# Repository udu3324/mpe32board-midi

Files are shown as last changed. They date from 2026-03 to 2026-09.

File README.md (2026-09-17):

# mpe32board-midi
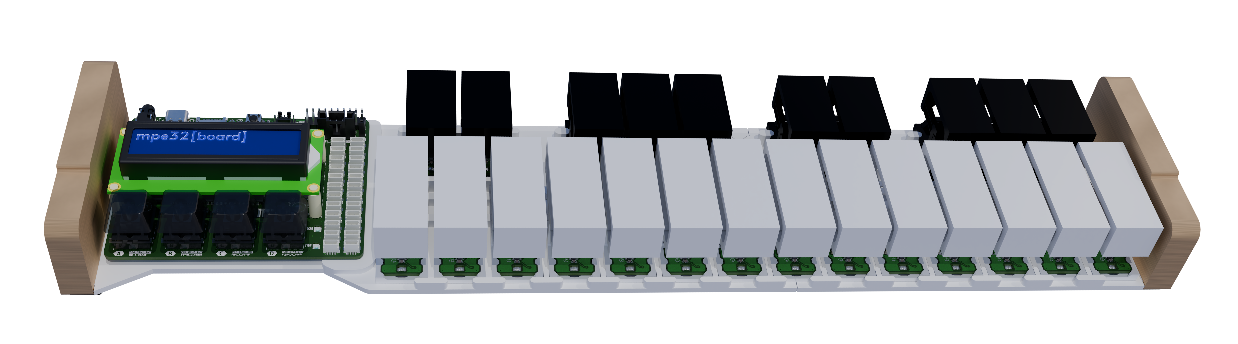
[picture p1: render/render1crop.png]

An expressive midi controller that has onboard sound processing with an expandable and hackable nature.
(v2 of [stm32pe-midi](https://github.com/udu3324/stm32pe-midi))

 * Built in DSP
 * Support for Programs and Sequencer
 * Hacker Header Exposed GPIO
 * Micro-SD Card Support
 * Onboard SDRAM for extended recording/memory

## Purpose
After making the [stm32pe-midi](https://github.com/udu3324/stm32pe-midi), I wanted to reflect at the problems I faced and the feature set I sacrificed out of it originally. I wanted to learn how ram works and the correct way to implement it, which I did for this project. I also wanted something that was more polished and structured better as the pcb dictated the rest of the design which lead to unfortunate design decisions. I instead designed everything in module-like components to allow more expansion and flexibility in the future.

## Zine Page
Some information is redacted on this export, DM me for the full version!
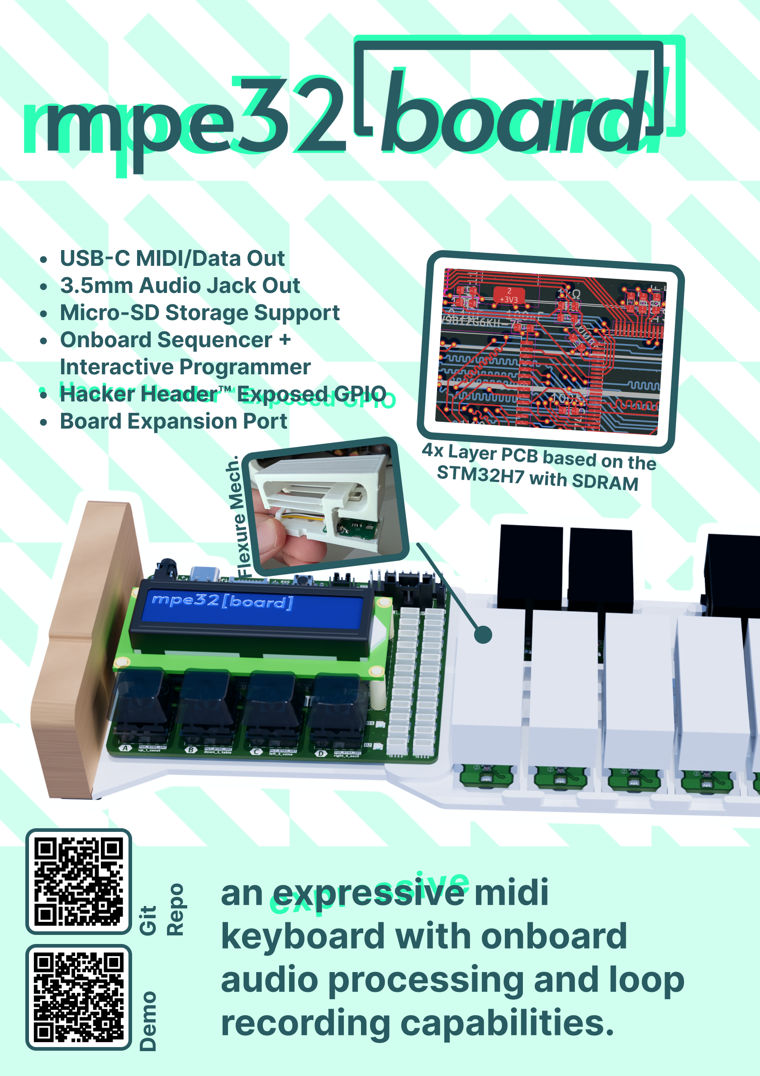
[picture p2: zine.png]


## Firmware
The firmware uses the stm32cubemx software to generate a .ioc of its pinout functions and its cmake gcc code template. I then chose Visual Studio Code as the choice of my IDE to code the rest in C/C++.

There is sample code [here](https://gist.github.com/udu3324/de9aada8e3ea0addc13870c6bbbebc0f) for trying out the mpe32sensors standalone on the Arduino platform.
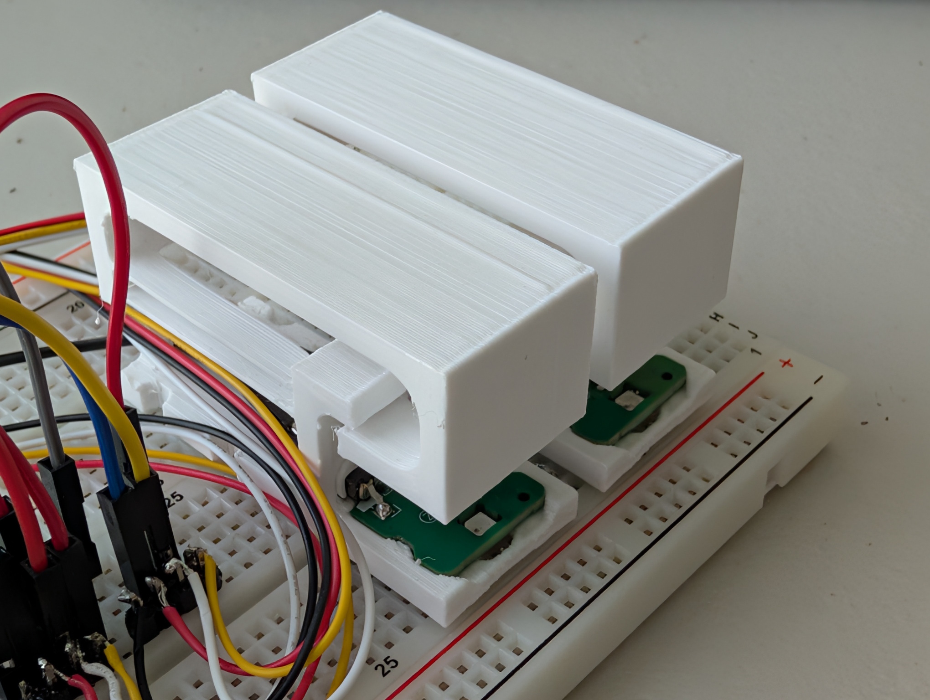
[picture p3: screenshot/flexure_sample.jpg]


### Libraries Used
 * https://github.com/hathach/tinyusb
 * https://github.com/jtainer/i2c-mux
 * https://github.com/berndoJ/libneopixel32
 * https://github.com/devOramaMan/stm32_TMAG5273 (modified/fixed)
 * https://github.com/alixahedi/i2c-lcd-stm32

## CAD
### Case
The case is a 3 part 3d-printed case that is screwed together with m3 screws, both being self-tapped and heat-set inserts. There are two wood block accents (or plywood) on the side screwed in too.
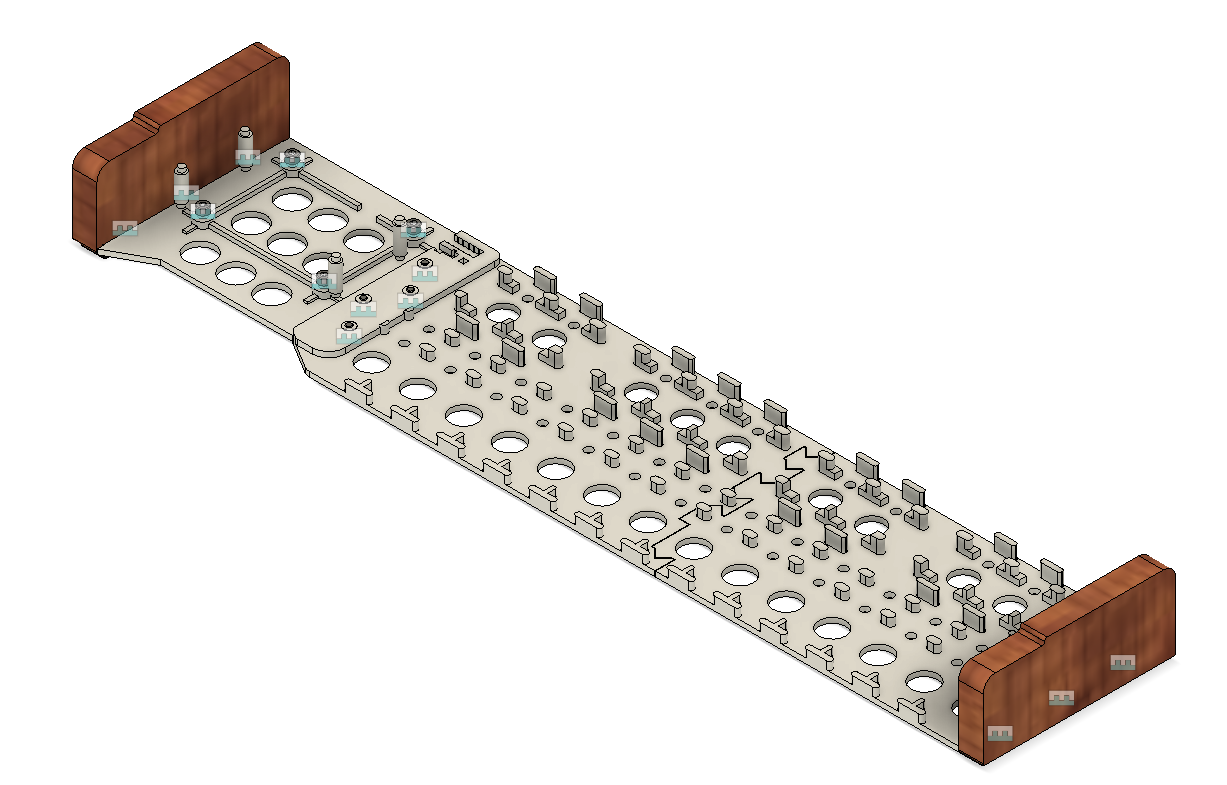
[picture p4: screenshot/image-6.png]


Each key is press fit and can also be screwed in with a m3 screw and nut if needed.
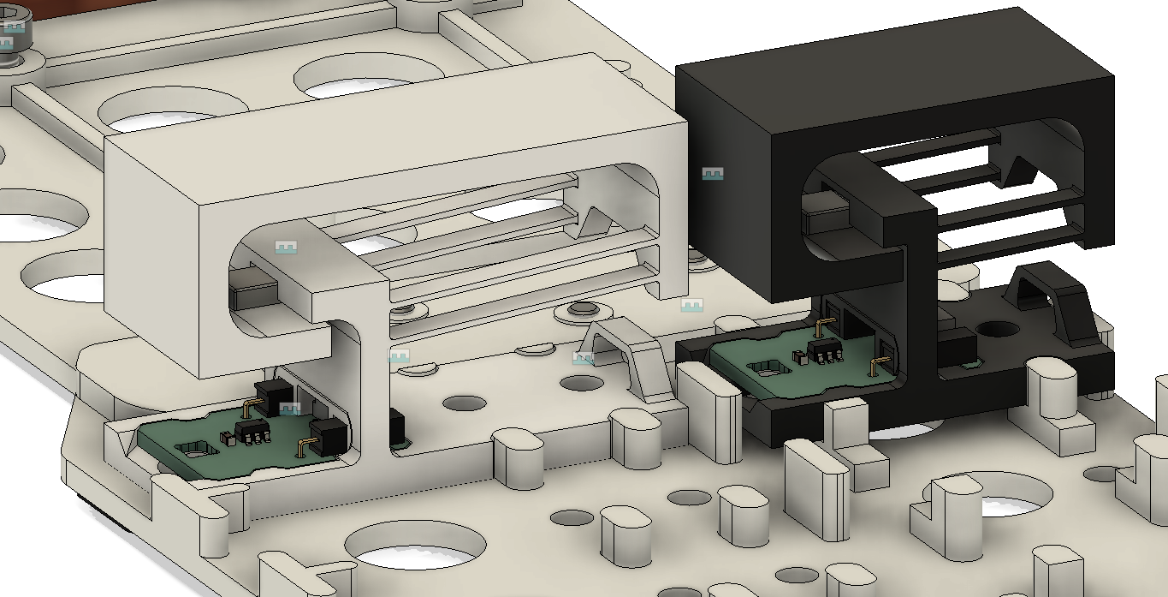
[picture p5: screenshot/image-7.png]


Due to my 3d-printer being too small, I have to cut the board in half to print. This is later adhered with uv-glue.
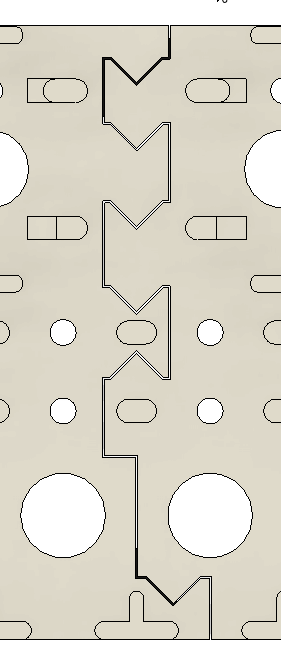
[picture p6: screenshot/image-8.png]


### Keys
The keys are compliant mechanisms that are designed to be 3d-printed with the least amount of post-processing. The flexure allows the key to move up and down as well as twist to allow pitch shifting.
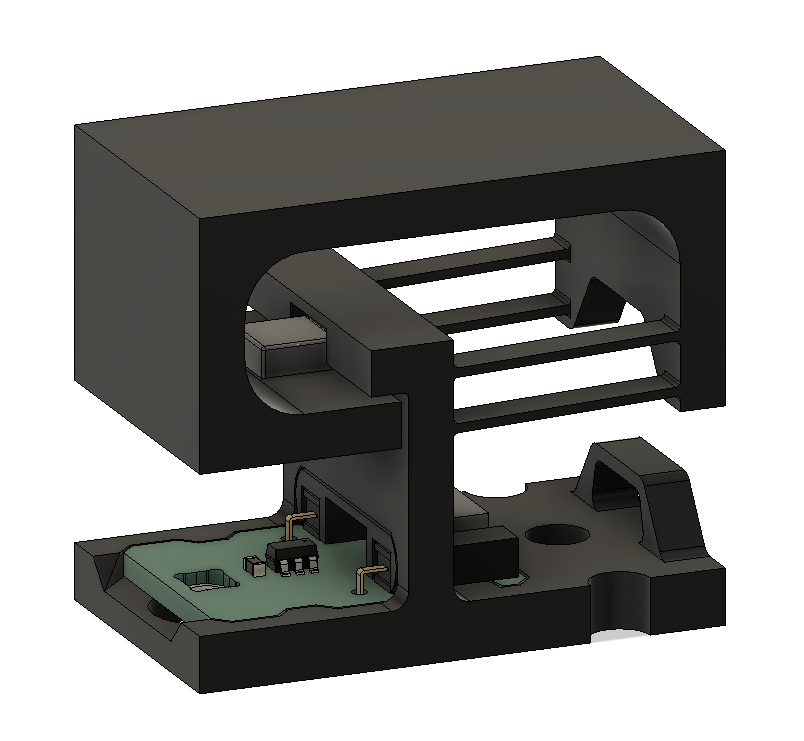
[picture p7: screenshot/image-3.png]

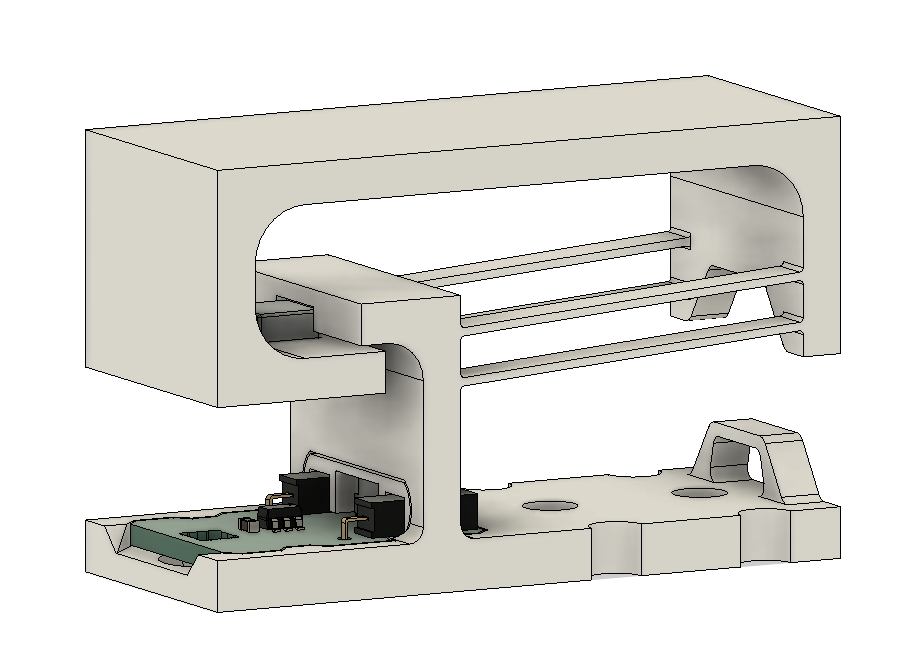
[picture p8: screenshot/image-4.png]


Another printed piece is included to hold down and fix the stm32sensor pcb in place.
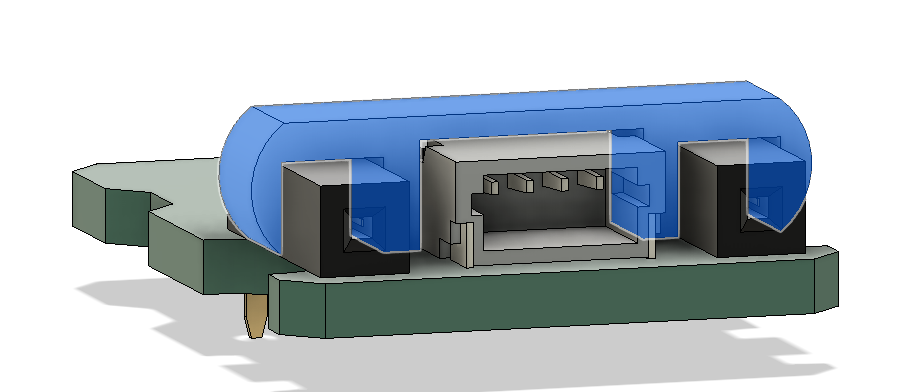
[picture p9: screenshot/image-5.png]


## PCB
I split my design into two boards. One being the "motherboard" called the stm32board which connects everything and has the mcu/ram/jtag for central control. The other is the sensor boards called the stm32sensor which connects through one of the 24 JST-SH-4x connectors that are on their own i2c line.

### stm32[board]
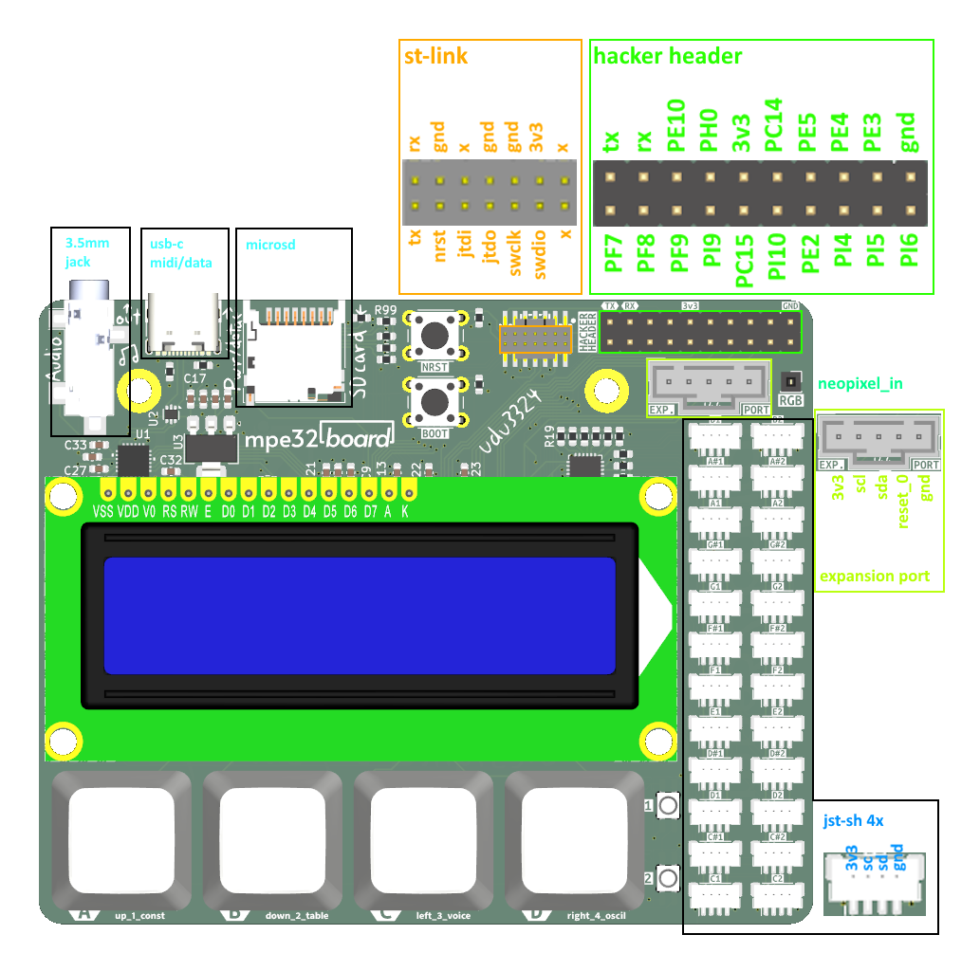
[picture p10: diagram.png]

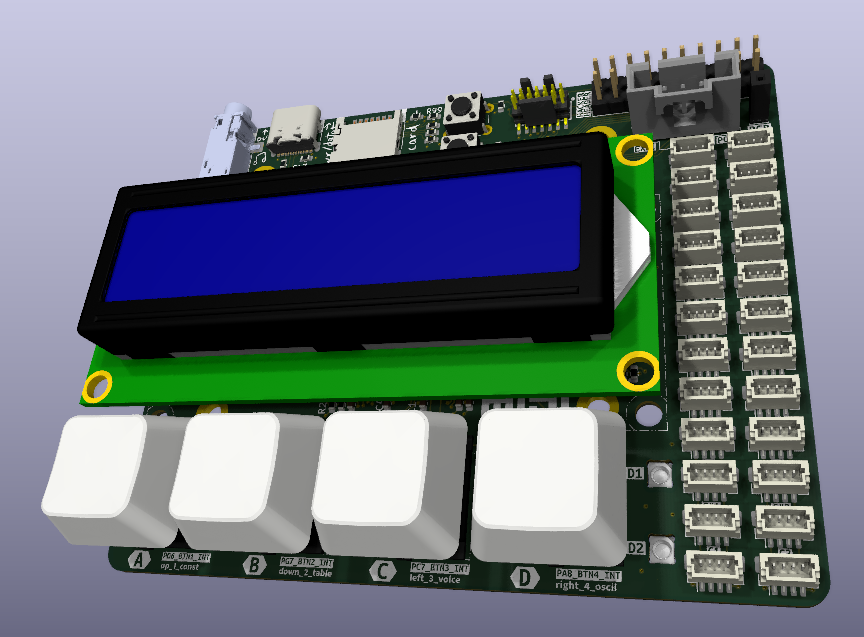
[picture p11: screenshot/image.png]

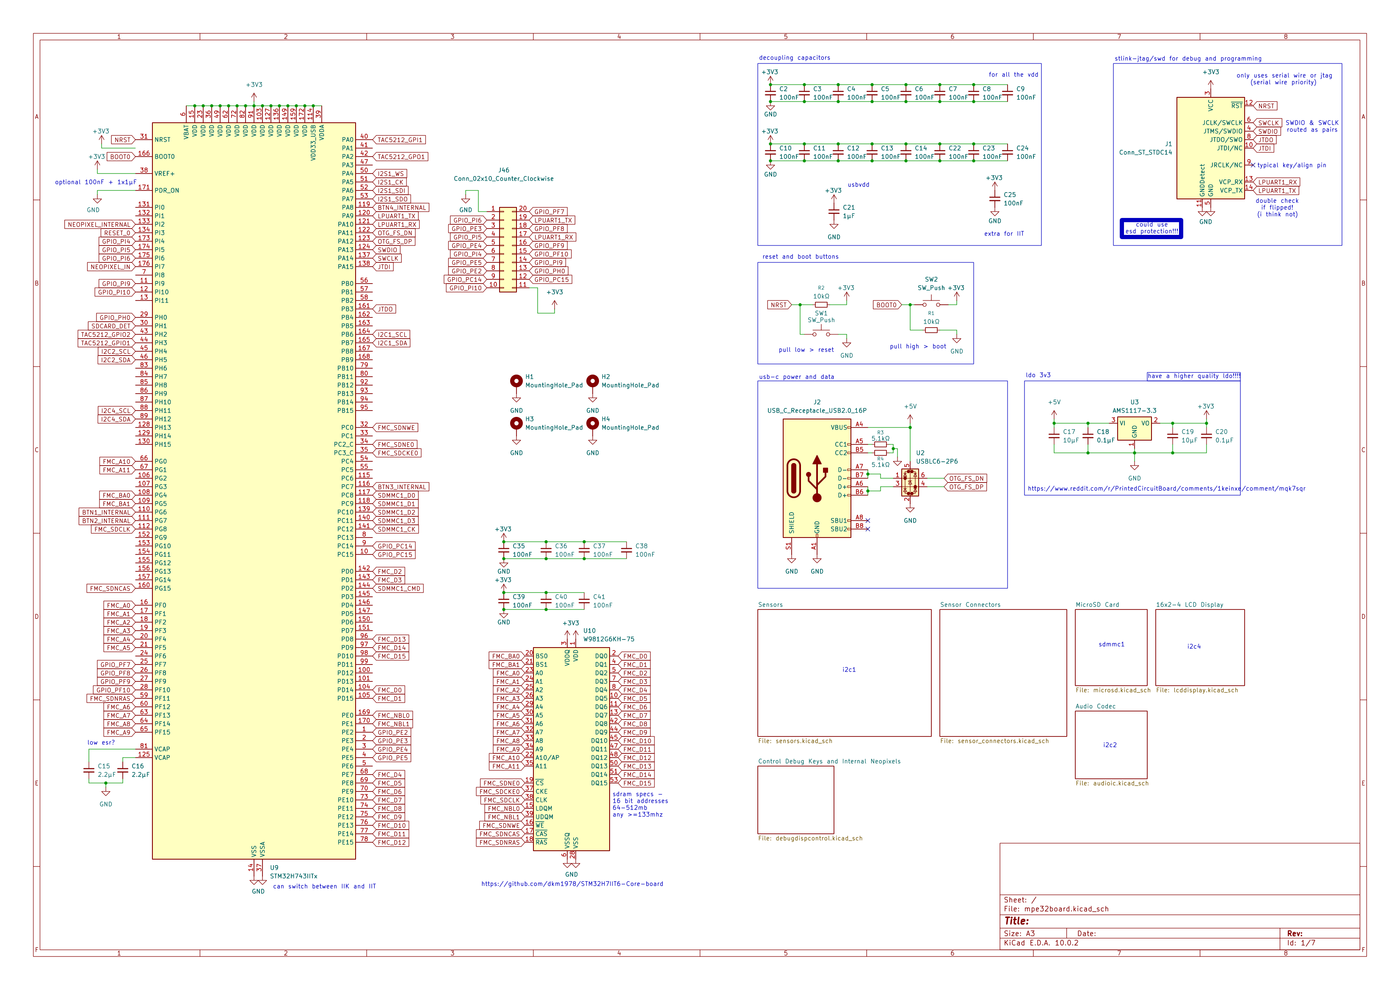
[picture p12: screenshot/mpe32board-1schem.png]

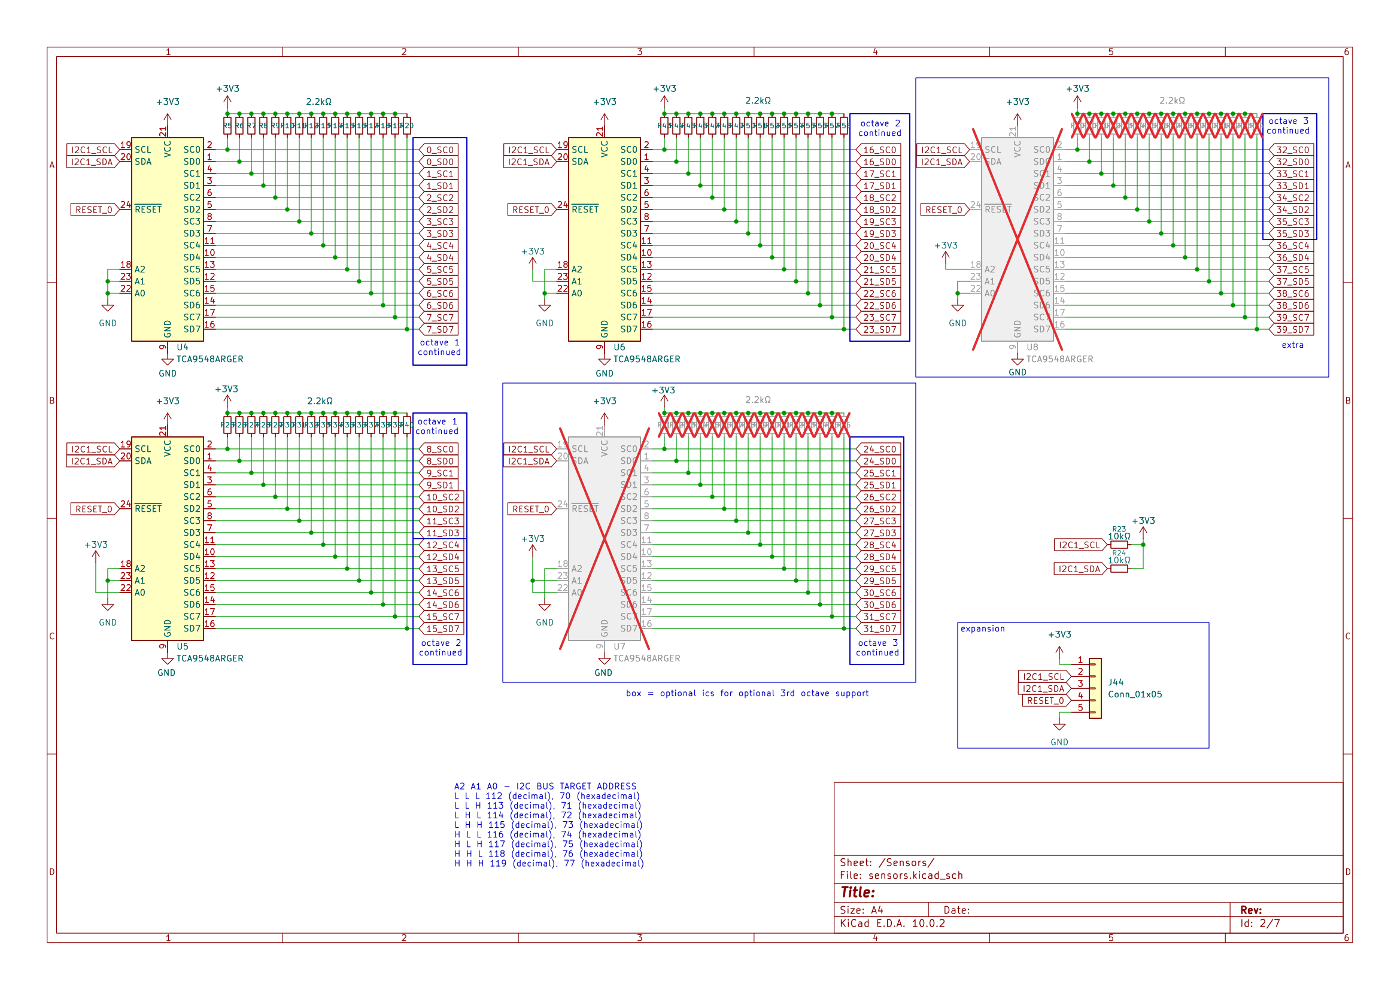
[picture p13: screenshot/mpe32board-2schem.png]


### stm32[sensor]
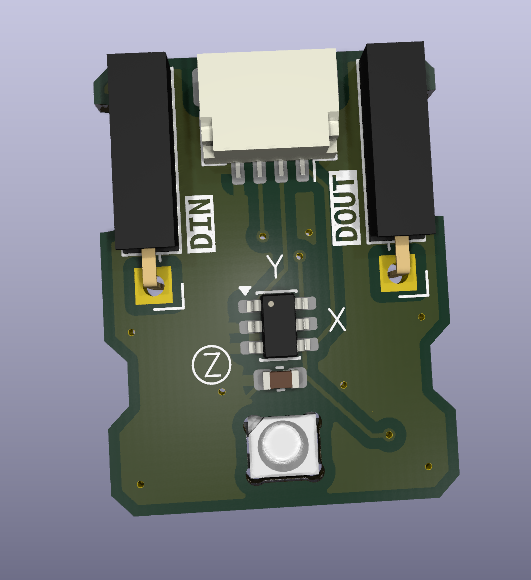
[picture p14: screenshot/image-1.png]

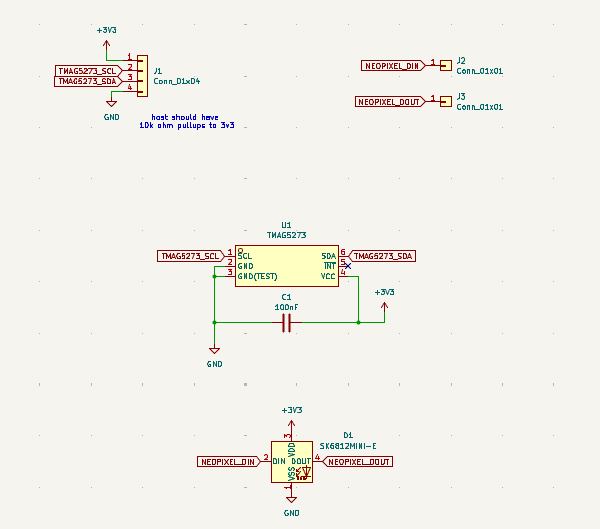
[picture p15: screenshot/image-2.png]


## BOM
The Bill of Materials can be viewed [here](https://docs.google.com/spreadsheets/d/1Ah6NNKW-CTIdOJtxNPdxd3ZnzDfgMl2LX2XapnXmrVo/edit).

### Build Steps
1. Get all materials ready and 3d printed
2. Post-process any 3d-prints if needed and insert heat set inserts for m3 screws
3. Assemble the pcb if not PCBA
4. Assemble all sensor boards into key housings and holder
5. Add LCD to stm32board and solder onto header
6. Assemble all keys and stm32board onto case, while also wire routing carefully
7. Screw on accent wood blocks
8. Flash firmware onto board
9. Done! Plug and play into your host device and favorite DAW

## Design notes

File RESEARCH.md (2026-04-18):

mpe32board-midi research

# features

midi out to pc
audio out to pc (onboard synth/dsp)
gpio exposed
easy tinkering with

(optional) microsd slot

# electronics

## main board

stm32h743 (good processing power)

i need a mcu that is:

* in stock
* supports sdram
* has good flash space

stm32h743ag
stm32h743ai
stm32h743ig

stm32h743xg
stm32h743xi

stm32h753ii

stm32h753ai (4 in stock) (lfbga169)
stm32h743ii (2k in stock) (lqfp176)
stm32h753xi (187 in stock) (tfbga240+25)

going with stm32h743ii

^ good option, better than the 750 which has little flash

supports a 16x2 lcd display (headers for it)

https://community.st.com/t5/stm32-mcus/how-to-set-up-the-fmc-peripheral-to-interface-with-the-sdram/ta-p/49457
https://www.youtube.com/watch?v=h28D4AaPSjg
64mb ram (SDRAM) (look at 3.15 on datasheet)
has to run 100mhz, can be underclocked, 90-tfbga footprint
also i hope i can trace this well

a bunch of TCA9548A i2c muxes
!!!!!!!! check if memory could take up too much io for the muxes i need
^ im pretty sure im fine as the muxes can hardware set their addresses

https://electronics.stackexchange.com/questions/595103/stdc14-connector-pinout-for-st-link-v3-for-swd-debugging
stlink for easy debugging and flashing (under jtag/swd)
either use 10pin or 20pin
still requires external power (from usb c)

https://www.phippselectronics.com/interface-an-sd-card-through-sdio-on-the-stm32-blackpill-part-1/

microsd support

## hall effect sensor board

tmag5273
^ capacitor for it

https://www.thevfdcollective.com/blog/stm32-and-sk6812-rgbw-led
(optional) neopixel? (supply with 3v3 and 3v3 logic)

connector out > 3v3, gnd, tmag out, neopixel in, neopixel out (5)
OR
connector out > 3v3, gnd, tmag out
connector L > neopixel in
connector R > neopixel out (chain-like connection)

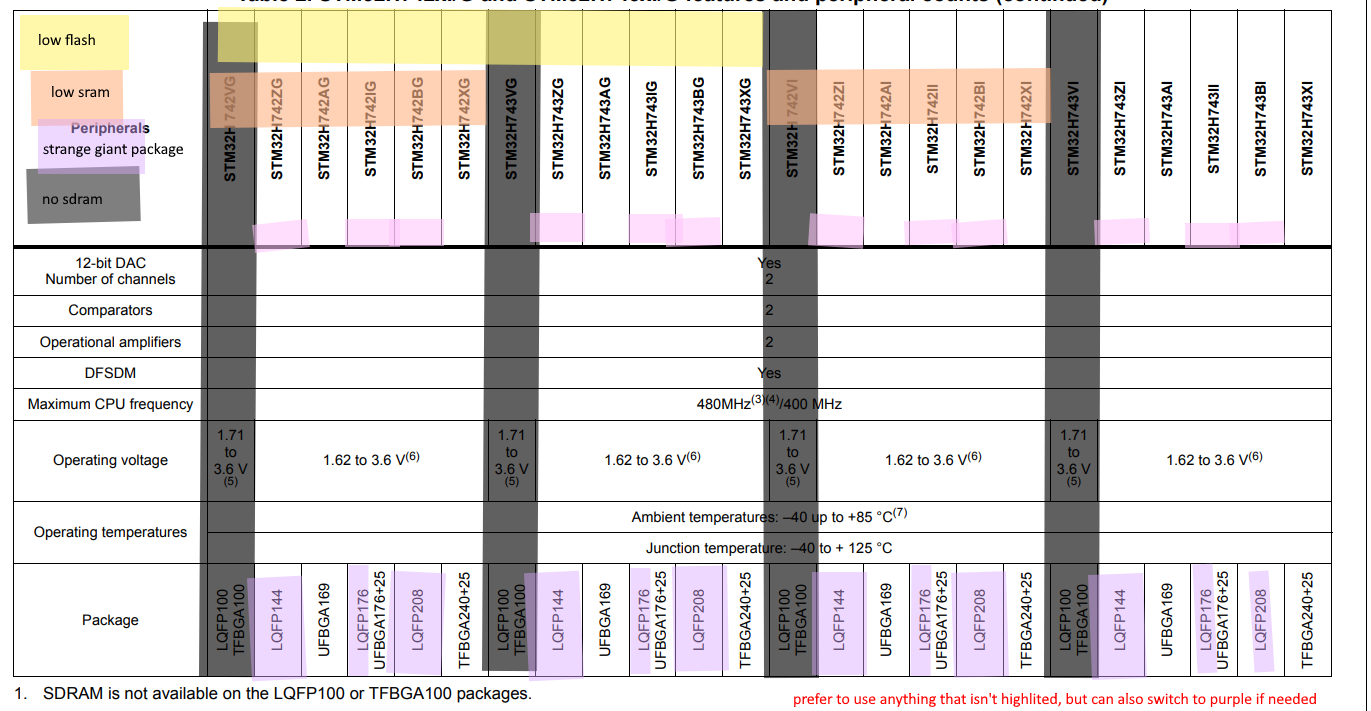
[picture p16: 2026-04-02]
stm32h7.png

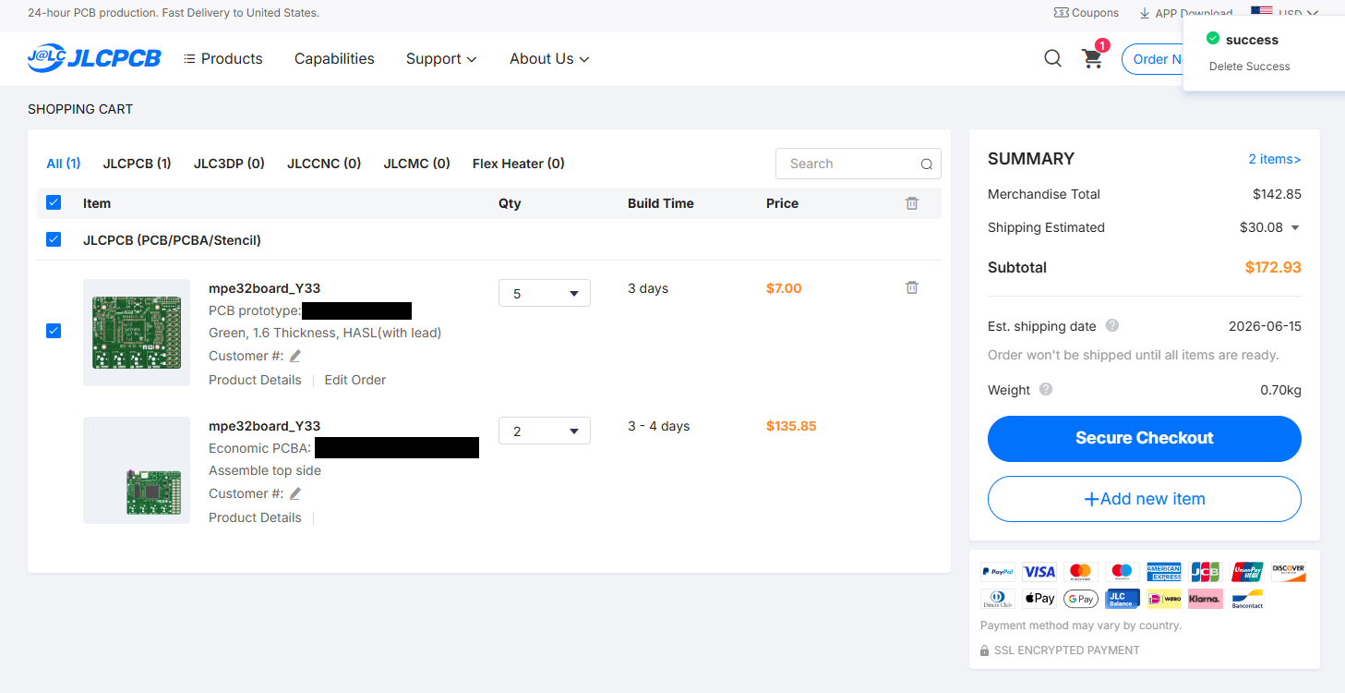
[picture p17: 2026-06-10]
cart/jlcpcb-mpe32board subtotal.png

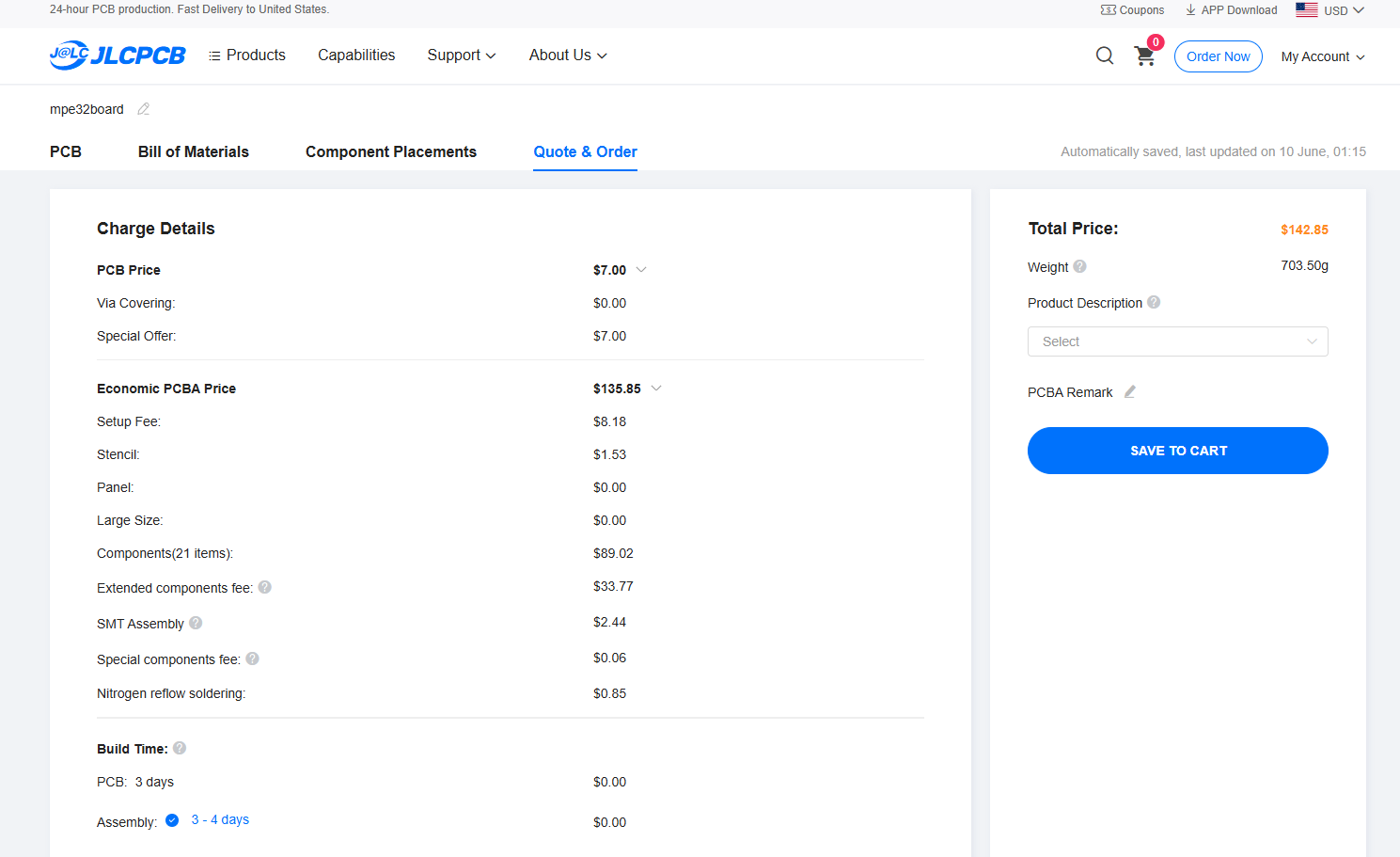
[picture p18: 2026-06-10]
cart/jlcpcb-mpe32board price breakdown.png

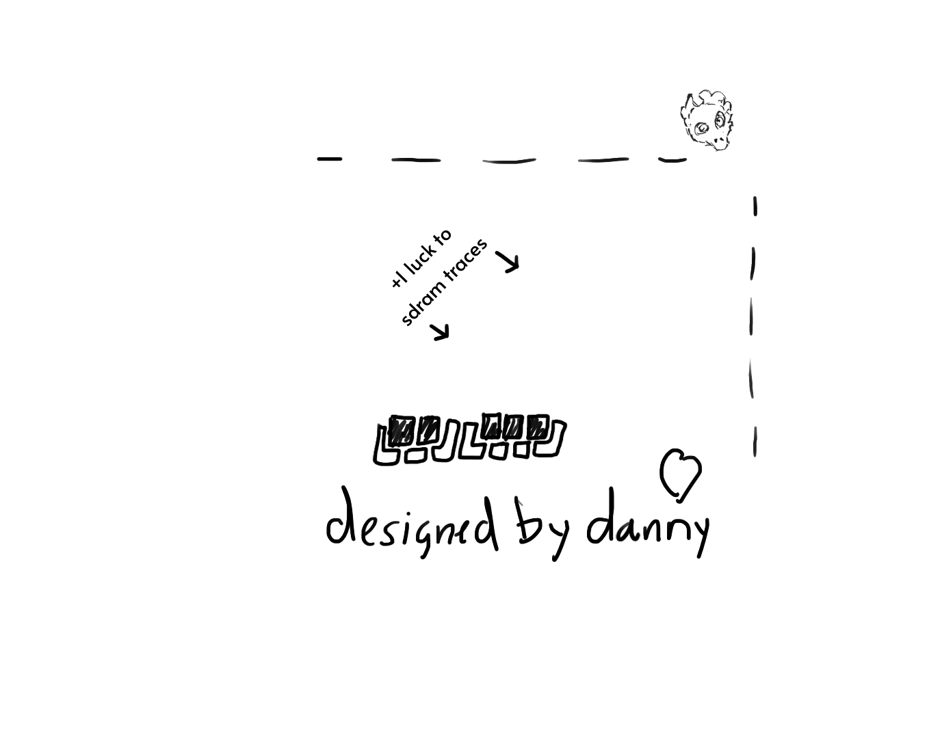
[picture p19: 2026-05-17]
pcb/mpe32board-B_Silkscreen.png

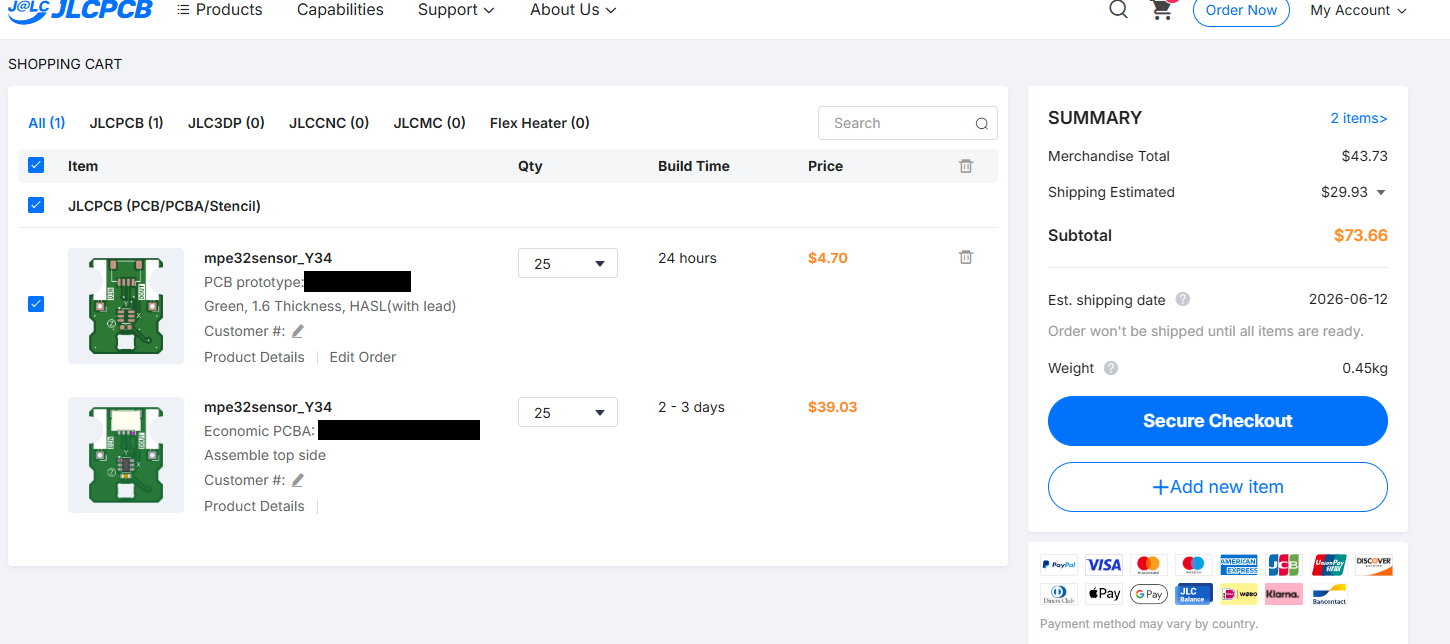
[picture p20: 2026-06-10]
cart/jlcpcb-mpe32sensor subtotal.png

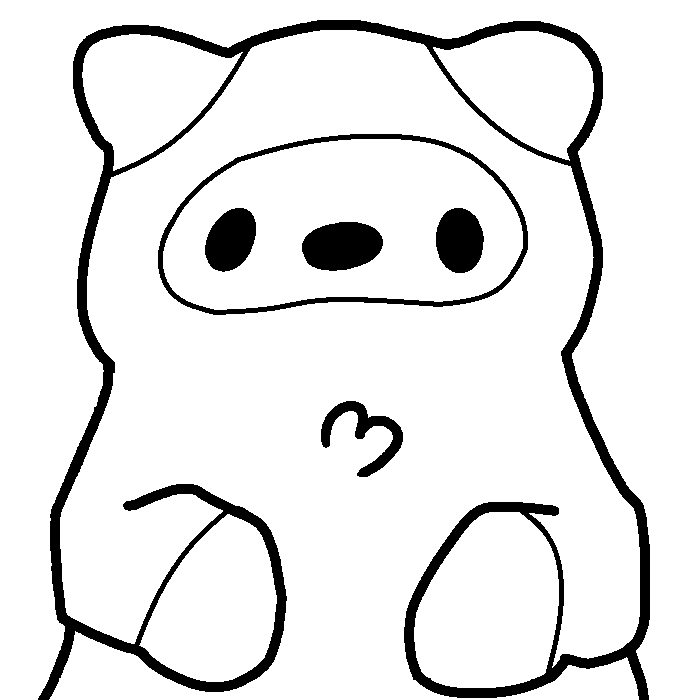
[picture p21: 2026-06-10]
pcb/soup.png

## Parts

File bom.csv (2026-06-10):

Part | Description | URL | URL Note | Price | Quantity (reflecting part q, not product q) | Sourcing | Subtotals
neodymium magnet | 5mm cube | https://www.amazon.com/dp/B0GTTXC3FT | pack of 60 | 9.99 | 24 |  | 9.99
Key Large | 3d printed |  |  |  | 14 | will print
Key Small | ~ |  |  |  | 10 | will print
LCD Spacer | ~ |  |  |  | 4 | will print
Case Right | ~ |  |  |  | 1 | will print
Case Left | ~ |  |  |  | 1 | will print
Case | ~ |  |  |  | 1 | will print
UV Glue |  | https://www.amazon.com/dp/B018IBEHQU |  | 13.95 | 1 | already have
plywood | 12mm thick | https://makerstock.com/products/baltic-birch-plywood-uv-prefinished-b-bb-finished-both-sides-copy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 | 3x3in | 4.95 | 2 | already have | 9.9
m3 heatset inserts |  | https://www.adafruit.com/product/4255 | pack of 50 | 5.95 | 8 |  | 5.95
m3 6mm screw |  | https://www.mcmaster.com/91292A111/ | pack of 100 | 12.71 | 14 |  | 12.71
m3 4mm screw |  | https://www.mcmaster.com/91292A109/ | pack of 50 | 3.86 | 14 | already have | 3.86
CN0295D | lcd screen | https://www.digikey.com/en/products/detail/sunfounder/CN0295D/18668612 |  | 9.13 | 1 | already have | 9.13
SK6812MINI-E |  |  |  |  | 4 | already have | 2.95
hotswap switch socket |  | https://www.adafruit.com/product/4958 | comes in pack of 20 | 4.95 | 4 |  | 4.95
key switches |  | https://www.aliexpress.us/item/3256808099380919.html?curPageLogUid=pP8MKuu5kHOB | comes in a pack of 8 (priced welcome deal) | 0.99 | 4 | already have | 0.99
4x 2.54 male header |  | https://www.mouser.com/ProductDetail/Samtec/MTSW-104-07-F-S-155?qs=PB6%2FjmICvI1FPDxv9fFH%252BQ%3D%3D |  | 0.31 | 1 | already have | 0.31
5x female molex conn |  | https://www.mouser.com/ProductDetail/Molex/171971-0005?qs=lc2O%252BfHJPVaHzX1glCYU2g%3D%3D |  | 1.37 | 1 |  | 1.37
1x 2.54 female header |  | https://www.mouser.com/ProductDetail/Samtec/SSA-101-S-G?qs=rU5fayqh%252BE15kAKORo1KGg%3D%3D |  | 0.41 | 1 |  | 0.41
10x2 2.54 male header |  | https://www.mouser.com/ProductDetail/Amphenol-FCI/77313-824-10LF?qs=xJiur%252Bgubk0jGbvndcgeKw%3D%3D |  | 0.56 | 1 |  | 0.56
6mm push button |  | https://www.mouser.com/ProductDetail/CK/PTS645SH43-2-LFS?qs=rqnA19JZHeR58R%2F%2FUQmolQ%3D%3D |  | 0.27 | 2 | already have | 0.54
PCB board | JLCPCB PCBA |  | grand total | 254.56 | 1 |  | 254.56
SK6812MINI-E |  | https://www.mouser.com/ProductDetail/Adafruit/4960?qs=pBJMDPsKWf1Q%252BqeEoLnQjA%3D%3D | comes in pack of 10 | 2.95 | 24 |  | 8.85
2.54 1x female header | needs to be bent to horizontal | https://www.mouser.com/ProductDetail/Samtec/SSA-101-S-G?qs=rU5fayqh%252BE15kAKORo1KGg%3D%3D | 24*2 needed | 0.41 | 48 |  | 19.68
PCB sensor | JLCPCB PCBA |  | grand total (can't order exactly 24) | 80.54 | 25 |  | 80.54
 |  |  |  |  |  |  | 427.25 | TOTAL
 |  |  |  |  |  |  | 399.57 | TOTAL without the things i have already

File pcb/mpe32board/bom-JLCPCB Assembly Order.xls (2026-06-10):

JLCPCB BOM Tool - BOM Matching
BOM name：bom-JLCPCB Assembly Order.xlsx |  |  | Download Time：2026-06-10 14:11:54 |  |  |  | * Our matching results are updated in real-time, but stock and prices may change. If it's been over 24 hours, please re-match before placing your order.
PCB Assembled Qty：5 |  |  | Est. Total Price：89.6339
Your BOM |  |  |  |  | Matched Parts |  |  |  |  |  |  | Order Information
Top Designator | Bottom Designator | Comment | Footprint | JLCPCB Part # | Matches | Part # | Manufacturer | Footprint | Description | Category | Warning | JLCPCB Part # | Product link | Lib Type | Qty | Source | Total Price ($)
C10,C11,C12,C13,C14,C2,C22,C23,C24,C25,C3,C35,C36,C37,C38,C39,C4,C40,C41,C5,C6,C7,C8,C9 |  | 100nF | 0603 |  | Unconfirmed | CC0603KRX7R9BB104 | YAGEO | 0603 | 100nF 50V X7R ±10% 0603 Multilayer Ceramic Capacitors MLCC - SMD/SMT ROHS | Multilayer Ceramic Capacitors MLCC - SMD/SMT | 1.Multiple lines in the BOM have been matched to the same part. Please check if the matching is correct. ; | C14663 | https://jlcpcb.com/partdetail/YAGEO-CC0603KRX7R9BB104/C14663 | Basic | 58 | 58 JLCPCB | 0.6148
C18,C20,C27,C29,C31 |  | 0.1μF | 0603 |  | Unconfirmed | CC0603KRX7R9BB104 | YAGEO | 0603 | 100nF 50V X7R ±10% 0603 Multilayer Ceramic Capacitors MLCC - SMD/SMT ROHS | Multilayer Ceramic Capacitors MLCC - SMD/SMT | 1.The comment (CC0603KRX7R9BB104) of this part does not match the one (0.1μF) provided in your BOM. Please confirm; 2.Multiple lines in the BOM have been matched to the same part. Please check if the matching is correct. ; | C14663 | https://jlcpcb.com/partdetail/YAGEO-CC0603KRX7R9BB104/C14663 | Basic | 58 | 58 JLCPCB | 0.6148
C15,C16 |  | 2.2μF | 0603 |  | Unconfirmed | CL10A225KO8NNNC | Samsung Electro-Mechanics | 0603 | 16V 2.2uF X5R ±10% 0603 Multilayer Ceramic Capacitors MLCC - SMD/SMT ROHS | Multilayer Ceramic Capacitors MLCC - SMD/SMT | 1.The comment (CL10A225KO8NNNC) of this part does not match the one (2.2μF) provided in your BOM. Please confirm; | C23630 | https://jlcpcb.com/partdetail/24366-CL10A225KO8NNNC/C23630 | Basic | 4 | 4 JLCPCB | 0.0368
C17,C19,C26,C30,C32 |  | 10μF | 0603 |  | Unconfirmed | CL10A106KP8NNNC | Samsung Electro-Mechanics | 0603 | 10V 10uF X5R ±10% 0603 Multilayer Ceramic Capacitors MLCC - SMD/SMT ROHS | Multilayer Ceramic Capacitors MLCC - SMD/SMT | 1.The comment (CL10A106KP8NNNC) of this part does not match the one (10μF) provided in your BOM. Please confirm; | C19702 | https://jlcpcb.com/partdetail/20411-CL10A106KP8NNNC/C19702 | Basic | 10 | 10 JLCPCB | 0.155
C21,C28 |  | 1μF | 0603 |  | Unconfirmed | CL10A105KB8NNNC | Samsung Electro-Mechanics | 0603 | 1uF 50V X5R ±10% 0603 Multilayer Ceramic Capacitors MLCC - SMD/SMT ROHS | Multilayer Ceramic Capacitors MLCC - SMD/SMT | 1.The comment (CL10A105KB8NNNC) of this part does not match the one (1μF) provided in your BOM. Please confirm; | C15849 | https://jlcpcb.com/partdetail/16531-CL10A105KB8NNNC/C15849 | Basic | 4 | 4 JLCPCB | 0.0432
C33,C34 |  | 47μF | 0603 |  | Select by Customer | GRM188R60J476ME15D | Murata Electronics | 0603 | 47uF 6.3V X5R ±20% 0603 Multilayer Ceramic Capacitors MLCC - SMD/SMT ROHS | Multilayer Ceramic Capacitors MLCC - SMD/SMT | 1.The comment (GRM188R60J476ME15D) of this part does not match the one (47μF) provided in your BOM. Please confirm; | C140782 | https://jlcpcb.com/partdetail/152108-GRM188R60J476ME15D/C140782 | Extended | 8 | 8 JLCPCB | 1.0264
J1 |  | Conn_ST_STDC14 | CONN-SMD_14P-P1.27_FTSH-107-01-F-DV-K-P-TR |  | Select by Customer | FTSH-107-01-F-DV-K-P-TR | Samtec | SMD,P=1.27mm | -55℃~+125℃ 1.27mm 14P 2 2x7P 3.05mm 3.4A Black Gold Phosphor bronze Pin Header Surface Mount,Vertical SMD,P=1.27mm Pin Headers ROHS | Pin Headers | 1.The comment (FTSH-107-01-F-DV-K-P-TR) of this part does not match the one (Conn_ST_STDC14) provided in your BOM. Please confirm; | C5276598 | https://jlcpcb.com/partdetail/Samtec-FTSH_107_01_F_DV_K_PTR/C5276598 | Extended | 2 | 2 JLCPCB | 6.6228
J2 |  | USB_C_Receptacle_USB2.0_16P | USB_C_Receptacle_GCT_USB4105-xx-A_16P_TopMnt_Horizontal |  | Select by Customer | USB4105-GF-A-120 | Global Connector Technology | SMD | -40℃~+85℃ 1 16P 48V 5A Black Female Type-C USB 2.0 SMD USB Connectors ROHS | USB Connectors |  | C5184243 | https://jlcpcb.com/partdetail/5849584-USB4105_GF_A120/C5184243 | Extended | 2 | 2 JLCPCB | 1.9534
J10,J11,J12,J13,J14,J15,J16,J17,J18,J19,J20,J21,J22,J23,J24,J25,J26,J27,J4,J5,J6,J7,J8,J9 |  | Conn_01x04 | JST_SH_BM04B-SRSS-TB_1x04-1MP_P1.00mm_Vertical |  | Select by Customer | BM04B-SRSS-TB(LF)(SN) | JST | SMD,P=1mm | -25℃~+85℃ 1 1A 1mm 1x4P 3.6mm 4 4.25mm 4P 50V 6mm Auxiliary Solder Pin Copper alloy PA SR Surface Mount,Vertical Tin UL94V-0 White SMD,P=1mm Wire To Board Connector ROHS | Wire To Board Connector |  | C160390 | https://jlcpcb.com/partdetail/JST-BM04B_SRSS_TB_LF_SN/C160390 | Extended | 48 | 48 JLCPCB | 11.1216
J48 |  | Micro_SD_Card_Det_Hirose_DM3AT | microSD_HC_Hirose_DM3D-SF |  | Select by Customer | DM3D-SF | HRS(Hirose) | SMD | -25℃~+85℃ 1.55mm Connector and Ejector MicroSD Card (TF Card) No Push-Pull SMD SD Card / Memory Card Connector ROHS | SD Card / Memory Card Connector |  | C719027 | https://jlcpcb.com/partdetail/HRS_Hirose-DM3DSF/C719027 | Extended | 2 | 2 JLCPCB | 2.8158
J49 |  | AudioJack3_SwitchT | Jack_3.5mm_CUI_SJ-3524-SMT_Horizontal |  | Select by Customer | SJ-3524-SMT-TR | CUI | SMD | SMD Audio Connectors ROHS | Audio Connectors (Headphones) |  | C20182907 | https://jlcpcb.com/partdetail/CUI-SJ_3524_SMTTR/C20182907 | Extended | 2 | 2 JLCPCB | 2.0886
R1,R2,R21,R22,R23,R24,R59,R60,R77,R78 |  | 10kΩ | 0603 |  | Select by System | 0603WAF1002T5E | UNI-ROYAL(Uniroyal Elec) | 0603 | -55℃~+155℃ 100mW 10kΩ 75V Thick Film Resistor ±1% ±100ppm/℃ 0603 Chip Resistor - Surface Mount ROHS | Chip Resistor - Surface Mount |  | C25804 | https://jlcpcb.com/partdetail/26547-0603WAF1002T5E/C25804 | Basic | 20 | 20 JLCPCB | 0.022
R3,R4 |  | 5.1kΩ | 0603 |  | Select by System | 0603WAF5101T5E | UNI-ROYAL(Uniroyal Elec) | 0603 | -55℃~+155℃ 100mW 5.1kΩ 75V Thick Film Resistor ±1% ±100ppm/℃ 0603 Chip Resistor - Surface Mount ROHS | Chip Resistor - Surface Mount |  | C23186 | https://jlcpcb.com/partdetail/23913-0603WAF5101T5E/C23186 | Basic | 4 | 4 JLCPCB | 0.0064
R10,R11,R12,R13,R14,R15,R16,R17,R18,R19,R20,R25,R26,R27,R28,R29,R30,R31,R32,R33,R34,R35,R36,R37,R38,R39,R40,R43,R44,R45,R46,R47,R48,R49,R5,R50,R51,R52,R53,R54,R55,R56,R57,R58,R6,R7,R8,R9 |  | 2.2kΩ | 0603 |  | Select by System | 0603WAF2201T5E | UNI-ROYAL(Uniroyal Elec) | 0603 | -55℃~+155℃ 100mW 2.2kΩ 75V Thick Film Resistor ±1% ±100ppm/℃ 0603 Chip Resistor - Surface Mount ROHS | Chip Resistor - Surface Mount |  | C4190 | https://jlcpcb.com/partdetail/4597-0603WAF2201T5E/C4190 | Basic | 96 | 96 JLCPCB | 0.144
R41,R42 |  | 1kΩ | 0603 |  | Select by System | 0603WAF1001T5E | UNI-ROYAL(Uniroyal Elec) | 0603 | -55℃~+155℃ 100mW 1kΩ 75V Thick Film Resistor ±1% ±100ppm/℃ 0603 Chip Resistor - Surface Mount ROHS | Chip Resistor - Surface Mount |  | C21190 | https://jlcpcb.com/partdetail/21904-0603WAF1001T5E/C21190 | Basic | 4 | 4 JLCPCB | 0.0064
R95,R96,R97,R98,R99 |  | 47kΩ | 0603 |  | Select by System | 0603WAF4702T5E | UNI-ROYAL(Uniroyal Elec) | 0603 | -55℃~+155℃ 100mW 47kΩ 75V Thick Film Resistor ±1% ±100ppm/℃ 0603 Chip Resistor - Surface Mount ROHS | Chip Resistor - Surface Mount |  | C25819 | https://jlcpcb.com/partdetail/26562-0603WAF4702T5E/C25819 | Basic | 10 | 10 JLCPCB | 0.014
U1 |  | TAC5212IRGER | VQFN24_RGE_CORNERPADS_TEX-L |  | Select by System | TAC5212IRGER | Texas Instruments | VQFN-24(4x4) | VQFN-24(4x4) Audio Interface ICs ROHS |  |  | C44853694 | https://jlcpcb.com/partdetail/TexasInstruments-TAC5212IRGER/C44853694 | Extended | 2 | 2 JLCPCB | 24.7984
U2 |  | USBLC6-2P6 | SOT-666 |  | Select by System | USBLC6-2P6 | STMicroelectronics | SOT-666-6 | -40℃~+125℃ 150nA 17V 2 3.5pF 5.25V 5A@8/20us 6V ESD IEC 61000-4-2 Unidirectional SOT-666-6 ESD and Surge Protection (TVS/ESD) ROHS | ESD And Surge Protection (TVS/ESD) |  | C15999 | https://jlcpcb.com/partdetail/STMicroelectronics-USBLC62P6/C15999 | Extended | 5 | 5 JLCPCB | 1.0975
U3 |  | AMS1117-3.3 | SOT-223-3_TabPin2 |  | Select by System | AMS1117-3.3 | Advanced Monolithic Systems | SOT-223 | -40℃~+125℃ 0.003%Vout 1 1.1V@(800mA) 15V 1A 3.3V 5mA 72dB@(120Hz) Fixed Over Current Protection、Short Circuit Protection、Thermal shutdown Positive SOT-223 Voltage Regulators - Linear, Low Drop Out (LDO) Regulators ROHS | Voltage Regulators - Linear, Low Drop Out (LDO) Regulators |  | C6186 | https://jlcpcb.com/partdetail/Advanced_MonolithicSystems-AMS1117_33/C6186 | Basic | 2 | 2 JLCPCB | 0.3934
U4,U5,U6 |  | TCA9548ARGER | Texas_RGE0024C_VQFN-24-1EP_4x4mm_P0.5mm_EP2.1x2.1mm |  | Select by System | TCA9548ARGER | Texas Instruments | VQFN-24-EP(4x4) | -40℃~+125℃ 1.65V~5.5V 2uA 400Kbps 80uA I2C、SMBus VQFN-24-EP(4x4) Interface - Specialized ROHS | Interface - Specialized |  | C555456 | https://jlcpcb.com/partdetail/TexasInstruments-TCA9548ARGER/C555456 | Extended | 6 | 6 JLCPCB | 4.9914
U9 |  | STM32H743IITx | LQFP-176_24x24mm_P0.5mm |  | Select by Customer | STM32H743IIT6 | STMicroelectronics | LQFP-176(24x24) | -40℃~+85℃ 1.62V~3.6V 12bit 140 16bit 1MB 2MB 32 Bit 480MHz ARM Cortex-M7 Built-in FLASH LQFP-176(24x24) Microcontrollers (MCU/MPU/SOC) ROHS | Microcontrollers (MCU/MPU/SOC) |  | C89597 | https://jlcpcb.com/partdetail/STMicroelectronics-STM32H743IIT6/C89597 | Extended | 2 | 2 JLCPCB | 16.869
U10 |  | W9812G6KH-75 | TSOP-II-54_22.2x10.16mm_P0.8mm |  | Select by Customer | W9812G6KH-6 | Winbond Elec | TSOPII-54-10.2mm | 0℃~+70℃ 128Mbit 166MHz 3V~3.6V TSOPII-54-10.2mm SDRAM ROHS | SDRAM |  | C62379 | https://jlcpcb.com/partdetail/WinbondElec-W9812G6KH6/C62379 | Extended | 2 | 2 JLCPCB | 14.1982
J3 |  | Conn_01x01_Socket | PinSocket_1x01_P2.54mm_Vertical |  | No matches | No Part Selected
J44 |  | Conn_01x05 | Molex_SL_171971-0005_1x05_P2.54mm_Vertical |  | No matches | No Part Selected
J45 |  | Conn_01x04_Socket | PinHeader_1x04_P2.54mm_Vertical |  | No matches | No Part Selected
J46 |  | Conn_02x10_Counter_Clockwise | PinHeader_2x10_P2.54mm_Vertical |  | No matches | No Part Selected
SW1,SW2 |  | SW_Push | SW_PUSH_6mm |  | No matches | No Part Selected

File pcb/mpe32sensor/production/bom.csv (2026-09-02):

Designator | Footprint | Quantity | Value | LCSC Part #
C1 | 0603 | 1 | 100nF | 100nF 0603 X7R
D1 | LED_SK6812MINI-E_3.2x2.8mm_P1.5mm_ReverseMount | 1 | SK6812MINI-E | SK6812MINI-E-012
J1 | JST_SH_SM04B-SRSS-TB_1x04-1MP_P1.00mm_Horizontal | 1 | Conn_01x04 | SM04B-SRSS-TB
J2, J3 | PinSocket_1x01_P2.54mm_Horizontal | 2 | Conn_01x01 | DNP
U1 | SOT-23-6 | 1 | TMAG5273 | C3716049

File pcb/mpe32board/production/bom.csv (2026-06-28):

Designator | Footprint | Quantity | Value | LCSC Part #
C1, C42 | 1206 | 2 | 10μF
C10, C11, C12, C13, C14, C17, C2, C22, C23, C24, C25, C3, C35, C36, C37, C38, C39, C4, C40, C41, C5, C6, C7, C8, C9 | 0603 | 25 | 100nF
C15, C16 | 0603 | 2 | 2.2μF
C21, C28, C43 | 0603 | 3 | 1μF
C26, C30, C32 | 0603 | 3 | 10μF
C27, C29, C31 | 0603 | 3 | 0.1μF
C33, C34 | 0603 | 2 | 47μF
CN0295D LCD | CN0295D | 1 | CN0295D
D1 | D_SMA | 1 | SS14
D2, D3, D4, D5, D6, D7 | LED_SK6812MINI-E_3.2x2.8mm_P1.5mm_ReverseMount | 6 | SK6812MINI-E
J1 | CONN-SMD_14P-P1.27_FTSH-107-01-F-DV-K-P-TR | 1 | Conn_ST_STDC14
J10, J11, J12, J13, J14, J15, J16, J17, J18, J19, J20, J21, J22, J23, J24, J25, J26, J27, J4, J5, J6, J7, J8, J9 | JST_SH_BM04B-SRSS-TB_1x04-1MP_P1.00mm_Vertical | 24 | Conn_01x04
J2 | USB_C_Receptacle_GCT_USB4105-xx-A_16P_TopMnt_Horizontal | 1 | USB_C_Receptacle_USB2.0_16P
J3 | PinSocket_1x01_P2.54mm_Vertical | 1 | Conn_01x01_Socket
J44 | Molex_SL_171971-0005_1x05_P2.54mm_Vertical | 1 | Conn_01x05
J45 | PinHeader_1x04_P2.54mm_Vertical | 1 | Conn_01x04_Socket
J46 | PinHeader_2x10_P2.54mm_Vertical | 1 | Conn_02x10_Counter_Clockwise
J48 | microSD_HC_Hirose_DM3D-SF | 1 | Micro_SD_Card_Det_Hirose_DM3AT
J49 | Jack_3.5mm_CUI_SJ-3524-SMT_Horizontal | 1 | AudioJack3_SwitchT
Q1, Q2 | SOT-23 | 2 | BSS138
R1, R100, R101, R2, R21, R22, R23, R24, R59, R60, R77, R78 | 0603 | 12 | 10kΩ
R10, R11, R12, R13, R14, R15, R16, R17, R18, R19, R20, R25, R26, R27, R28, R29, R30, R31, R32, R33, R34, R35, R36, R37, R38, R39, R40, R43, R44, R45, R46, R47, R48, R49, R5, R50, R51, R52, R53, R54, R55, R56, R57, R58, R6, R7, R8, R9 | 0603 | 48 | 2.2kΩ
R3, R4 | 0603 | 2 | 5.1kΩ
R41, R42 | 0603 | 2 | 1kΩ
R95, R96, R97, R98, R99 | 0603 | 5 | 47kΩ
SW1, SW2 | SW_PUSH_6mm | 2 | SW_Push
SW3, SW4, SW5, SW6 | MX-Hotswap-1U | 4 | SW_Push
U1 | VQFN24_RGE_CORNERPADS_TEX-L | 1 | TAC5212IRGER
U10 | TSOP-II-54_22.2x10.16mm_P0.8mm | 1 | W9812G6KH-75
U11 | SOT-223-3_TabPin2 | 1 | LM1117MP-3.3
U2 | SOT-666 | 1 | USBLC6-2P6
U4, U5, U6 | Texas_RGE0024C_VQFN-24-1EP_4x4mm_P0.5mm_EP2.1x2.1mm | 3 | TCA9548ARGER
U9 | LQFP-176_24x24mm_P0.5mm | 1 | STM32H743IITx

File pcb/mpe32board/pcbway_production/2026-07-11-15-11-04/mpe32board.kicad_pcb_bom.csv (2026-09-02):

Designator | Quantity | Value | Footprint | Package | MPN | DNP | Mount_Type | Description | KiLib_Generator
C1, C42 | 2 | 10μF | C_1206_3216Metric |  |  |  | smt | Polarized capacitor, small symbol Tantalum | SMD_2terminal_chip_molded
C10, C11, C12, C13, C14, C17, C2, C22, C23, C24, C25, C3, C35, C36, C37, C38, C39, C4, C40, C41, C5, C6, C7, C8, C9 | 25 | 100nF | C_0603_1608Metric |  |  |  | smt | Unpolarized capacitor, small symbol | SMD_2terminal_chip_molded
C15, C16 | 2 | 2.2μF | C_0603_1608Metric |  |  |  | smt | Unpolarized capacitor, small symbol | SMD_2terminal_chip_molded
C21, C28, C43 | 3 | 1μF | C_0603_1608Metric |  |  |  | smt | Unpolarized capacitor, small symbol | SMD_2terminal_chip_molded
C26, C30, C32 | 3 | 10μF | C_0603_1608Metric |  |  |  | smt | Unpolarized capacitor, small symbol | SMD_2terminal_chip_molded
C27, C29, C31 | 3 | 0.1μF | C_0603_1608Metric |  |  |  | smt | Unpolarized capacitor, small symbol | SMD_2terminal_chip_molded
C33, C34 | 2 | 47μF | C_0603_1608Metric |  |  |  | smt | Polarized capacitor, small symbol | SMD_2terminal_chip_molded
CN0295D LCD | 1 | CN0295D | CN0295D |  |  |  | tht
D1 | 1 | SS14 | D_SMA |  |  |  | smt | 40V 1A Schottky Diode, SMA
D2, D3, D4, D5, D6, D7 | 6 | SK6812MINI-E | LED_SK6812MINI-E_3.2x2.8mm_P1.5mm_ReverseMount |  |  |  | smt | RGB LED with integrated controller
J1 | 1 | Conn_ST_STDC14 | CONN-SMD_14P-P1.27_FTSH-107-01-F-DV-K-P-TR |  |  |  | tht | ST Debug Connector, standard ARM Cortex-M SWD and JTAG interface plus UART
J10, J11, J12, J13, J14, J15, J16, J17, J18, J19, J20, J21, J22, J23, J24, J25, J26, J27, J4, J5, J6, J7, J8, J9 | 24 | Conn_01x04 | JST_SH_BM04B-SRSS-TB_1x04-1MP_P1.00mm_Vertical |  |  |  | smt | Generic connector, single row, 01x04, script generated (kicad-library-utils/schlib/autogen/connector/) | connector/SMD_single_row_plus_mounting_pad
J2 | 1 | USB_C_Receptacle_USB2.0_16P | USB_C_Receptacle_GCT_USB4105-xx-A_16P_TopMnt_Horizontal |  |  |  | smt | USB 2.0-only 16P Type-C Receptacle connector
J3 | 1 | Conn_01x01_Socket | PinSocket_1x01_P2.54mm_Vertical |  |  |  | tht | Generic connector, single row, 01x01, script generated | connector/pin_header_socket
J44 | 1 | Conn_01x05 | Molex_SL_171971-0005_1x05_P2.54mm_Vertical |  |  |  | tht | Generic connector, single row, 01x05, script generated (kicad-library-utils/schlib/autogen/connector/) | connector/Molex
J45 | 1 | Conn_01x04_Socket | PinHeader_1x04_P2.54mm_Vertical |  |  |  | tht | Generic connector, single row, 01x04, script generated | connector/pin_header_socket
J46 | 1 | Conn_02x10_Counter_Clockwise | PinHeader_2x10_P2.54mm_Vertical |  |  |  | tht | Generic connector, double row, 02x10, counter clockwise pin numbering scheme (similar to DIP package numbering), script generated (kicad-library-utils/schlib/autogen/connector/) | connector/pin_header_socket
J48 | 1 | Micro_SD_Card_Det_Hirose_DM3AT | microSD_HC_Hirose_DM3D-SF |  |  |  | smt | Micro SD Card Socket with card detection pins
J49 | 1 | AudioJack3_SwitchT | Jack_3.5mm_CUI_SJ-3524-SMT_Horizontal |  |  |  | smt | Audio Jack, 3 Poles (Stereo / TRS), Switched T Pole (Normalling)
Q1, Q2 | 2 | BSS138 | SOT-23 |  |  |  | smt | 50V Vds, 0.22A Id, N-Channel MOSFET, SOT-23 | package/gullwing
R1, R100, R101, R2, R21, R22, R23, R24, R59, R60, R77, R78 | 12 | 10kΩ | R_0603_1608Metric |  |  |  | smt | Resistor, small symbol | SMD_2terminal_chip_molded
R10, R11, R12, R13, R14, R15, R16, R17, R18, R19, R20, R25, R26, R27, R28, R29, R30, R31, R32, R33, R34, R35, R36, R37, R38, R39, R40, R43, R44, R45, R46, R47, R48, R49, R5, R50, R51, R52, R53, R54, R55, R56, R57, R58, R6, R7, R8, R9 | 48 | 2.2kΩ | R_0603_1608Metric |  |  |  | smt | Resistor, small symbol | SMD_2terminal_chip_molded
R3, R4 | 2 | 5.1kΩ | R_0603_1608Metric |  |  |  | smt | Resistor, small symbol | SMD_2terminal_chip_molded
R41, R42 | 2 | 1kΩ | R_0603_1608Metric |  |  |  | smt | Resistor, small symbol | SMD_2terminal_chip_molded
R95, R96, R97, R98, R99 | 5 | 47kΩ | R_0603_1608Metric |  |  |  | smt | Resistor, small symbol | SMD_2terminal_chip_molded
SW1, SW2 | 2 | SW_Push | SW_PUSH_6mm |  |  |  | tht | Push button switch, generic, two pins
SW3, SW4, SW5, SW6 | 4 | SW_Push | MX-Hotswap-1U |  |  |  | smt | Push button switch, generic, two pins
U1 | 1 | TAC5212IRGER | VQFN24_RGE_CORNERPADS_TEX-L |  |  |  | smt
U10 | 1 | W9812G6KH-75 | TSOP-II-54_22.2x10.16mm_P0.8mm |  |  |  | smt | 128Mb Synchronous DRAM, 2 Mb x 16 b x 4 Banks, 133 MHz, TSOP-II-54
U11 | 1 | LM1117MP-3.3 | SOT-223-3_TabPin2 |  |  |  | smt | 800mA Low-Dropout Linear Regulator, 3.3V fixed output, SOT-223
U2 | 1 | USBLC6-2P6 | SOT-666 |  |  |  | smt | Very low capacitance ESD protection diode, 2 data-line, SOT-666
U4, U5, U6 | 3 | TCA9548ARGER | Texas_RGE0024C_VQFN-24-1EP_4x4mm_P0.5mm_EP2.1x2.1mm |  |  |  | smt | Low voltage 8-channel I2C switch with reset, QFN-24
U9 | 1 | STM32H743IITx | LQFP-176_24x24mm_P0.5mm |  |  |  | smt | STMicroelectronics Arm Cortex-M7 MCU, 2048KB flash, 1024KB RAM, 480 MHz, 1.62-3.6V, 140 GPIO, LQFP176 | package/gullwing

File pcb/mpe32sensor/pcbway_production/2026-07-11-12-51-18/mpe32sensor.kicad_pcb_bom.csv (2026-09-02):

Designator | Quantity | Value | Footprint | Package | MPN | DNP | Mount_Type | Description | KiLib_Generator | LCSC Part
C1 | 1 | 100nF | C_0603_1608Metric |  |  |  | smt | Unpolarized capacitor | SMD_2terminal_chip_molded
D1 | 1 | SK6812MINI-E | LED_SK6812MINI-E_3.2x2.8mm_P1.5mm_ReverseMount |  |  |  | smt | RGB LED with integrated controller
J1 | 1 | Conn_01x04 | JST_SH_SM04B-SRSS-TB_1x04-1MP_P1.00mm_Horizontal |  |  |  | smt | Generic connector, single row, 01x04, script generated (kicad-library-utils/schlib/autogen/connector/) | connector/SMD_single_row_plus_mounting_pad
J2, J3 | 2 | Conn_01x01 | PinSocket_1x01_P2.54mm_Horizontal |  |  |  | tht | Generic connector, single row, 01x01, script generated (kicad-library-utils/schlib/autogen/connector/) | connector/pin_header_socket
U1 | 1 | TMAG5273 | SOT-23-6 |  |  |  | smt |  | package/gullwing | C3716049

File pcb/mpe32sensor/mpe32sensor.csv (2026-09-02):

Reference | Qty | Value | DNP | Exclude from BOM | Exclude from Board | Footprint | Datasheet | MPN
C1 | 1 | 100nF |  |  |  | Capacitor_SMD:C_0603_1608Metric |  | 100nF 0603 X7R
D1 | 1 | SK6812MINI-E |  |  |  | LED_SMD:LED_SK6812MINI-E_3.2x2.8mm_P1.5mm_ReverseMount | https://www.lcsc.com/datasheet/C5149201.pdf | SK6812MINI-E-012
J1 | 1 | Conn_01x04 |  |  |  | Connector_JST:JST_SH_SM04B-SRSS-TB_1x04-1MP_P1.00mm_Horizontal |  | SM04B-SRSS-TB
J2,J3 | 2 | Conn_01x01 |  |  |  | Connector_PinSocket_2.54mm:PinSocket_1x01_P2.54mm_Horizontal |  | DNP
U1 | 1 | TMAG5273 |  |  |  | Package_TO_SOT_SMD:SOT-23-6 |  | TMAG5273A1

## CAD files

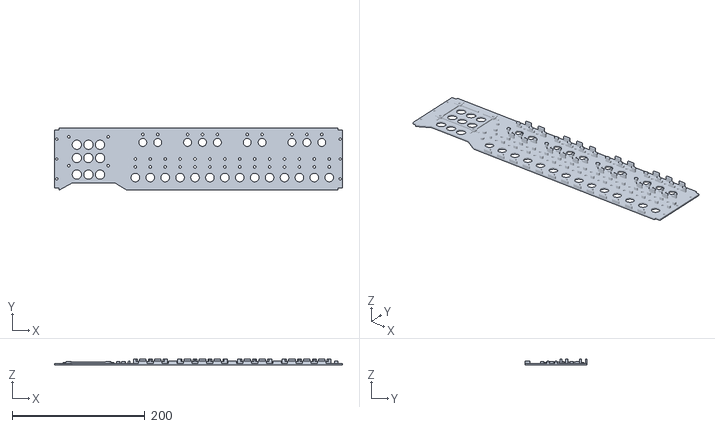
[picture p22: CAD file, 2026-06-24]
cad/Case_mpe32board full part.stl
434.5 x 94.0 x 9.11

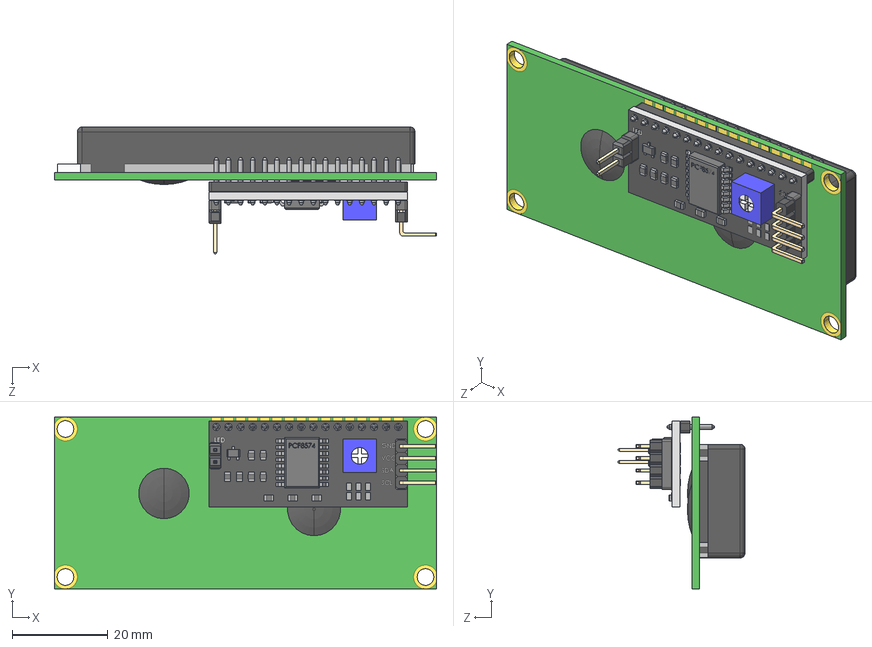
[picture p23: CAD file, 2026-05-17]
pcb/misc components/User Library-LCD1602 with I2C.STEP
80.0 x 36.0 x 26.6 mm
Imported
holder
pin x 2
User Library-PLS-4R gold

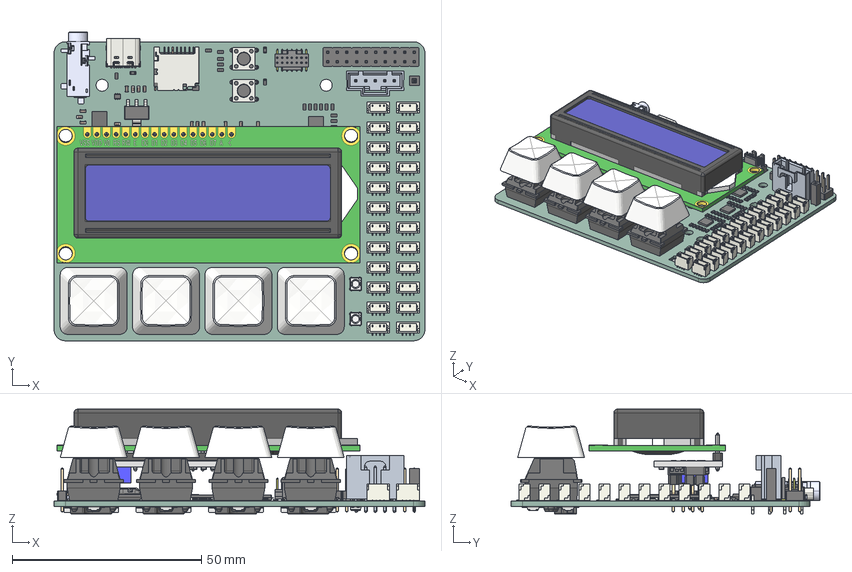
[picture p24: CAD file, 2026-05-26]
pcb/mpe32board/mpe32board.step
98.0 x 81.5 x 27.7 mm
JST_SH_BM04B-SRSS-TB_1x04-1MP_P1.00mm_Vertical x 24
C_0603_1608Metric x 40
R_0603_1608Metric x 67
Texas_RGE0024C_VQFN-24-1EP_4x4mm_P0.5mm_EP2.1x2.1mm x 3
Imported
holder
pin x 2
User Library-PLS-4R gold
SOT-223
microSD_HC_Hirose_DM3D-SF
CUI_DEVICES_SJ-3524-SMT-TR
LQFP-176_24x24mm_P0.5mm
CONN-SMD_14P-P1.27_FTSH-107-01-F-DV-K-P-TR
TSOP-II-54_22.2x10.16mm_P0.8mm
USB_C_Receptacle_16P_TopMnt_Horizontal_GCT_USB4105-xx-A
PinSocket_1x01_P2.54mm_Vertical
SOT_666
SW_PUSH_6mm x 2
PinHeader_2x10_P254mm_Vertical
PinHeader_1x04_P254mm_Vertical
Pin1 x 6
Pin2 x 6
Pin3 x 6
Pin4 x 6
Kailh Socket v12 x 4
xdakeycap v3 x 4
mpe32board_PCB

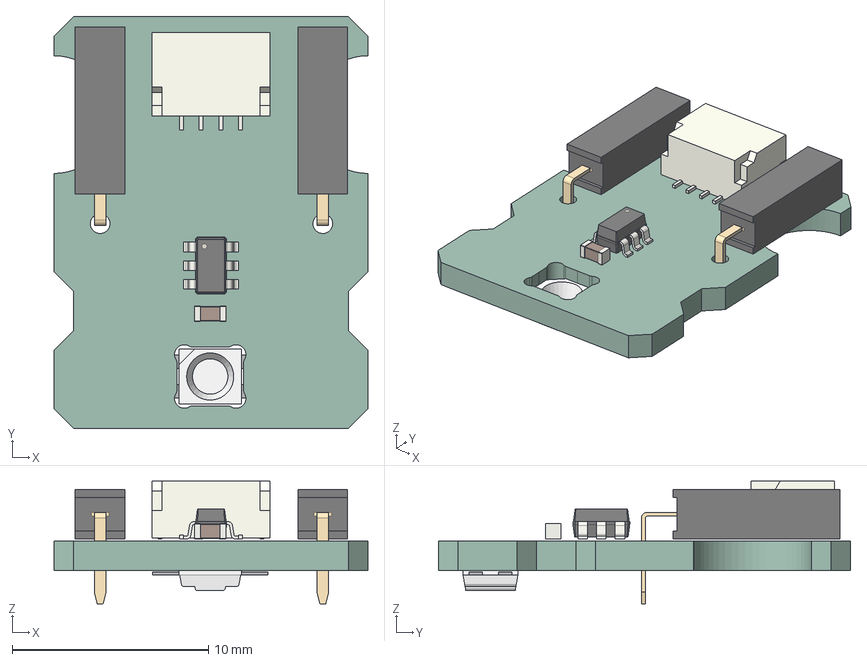
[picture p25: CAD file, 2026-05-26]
pcb/mpe32sensor/mpe32sensor.step
16.0 x 21.0 x 6.26 mm
PinSocket_1x01_P2.54mm_Horizontal x 2
JST_SH_SM04B-SRSS-TB_1x04-1MP_P1.00mm_Horizontal
C_0603_1608Metric
SOT-23-6
Pin1
Pin2
Pin3
Pin4
mpe32sensor_PCB

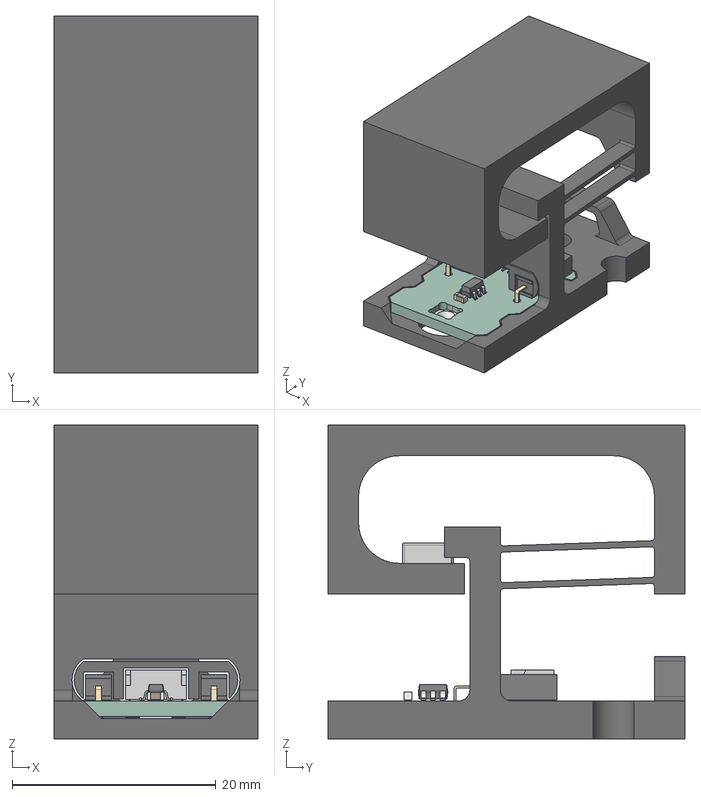
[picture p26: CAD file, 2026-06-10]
cad/mpe32sensor key small.step
20.0 x 35.0 x 30.8 mm
PinSocket_1x01_P2.54mm_Horizontal_1 x 2
JST_SH_SM04B-SRSS-TB_1x04-1MP_P1.00mm_Horizontal_1
C_0603_1608Metric_1
SOT-23-6_1
Pin1
Pin2
Pin3
Pin4
mpe32sensor_PCB

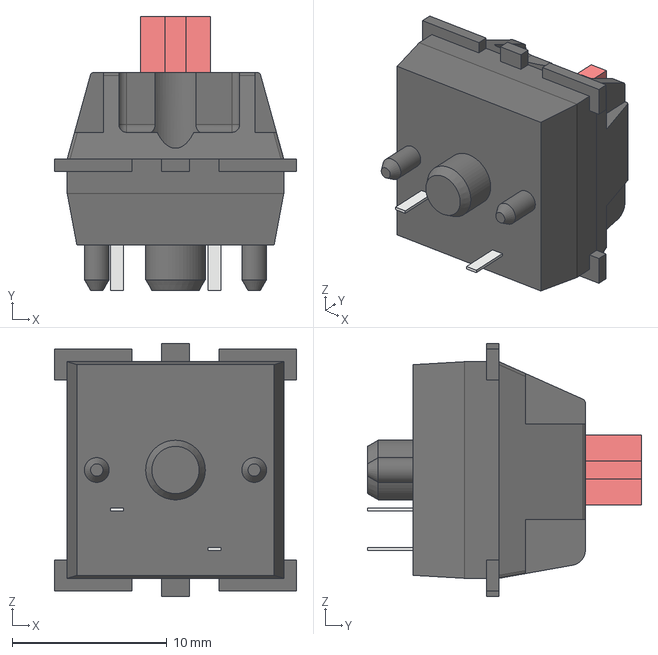
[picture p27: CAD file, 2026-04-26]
pcb/misc components/switch.step
15.6 x 17.7 x 16.3 mm

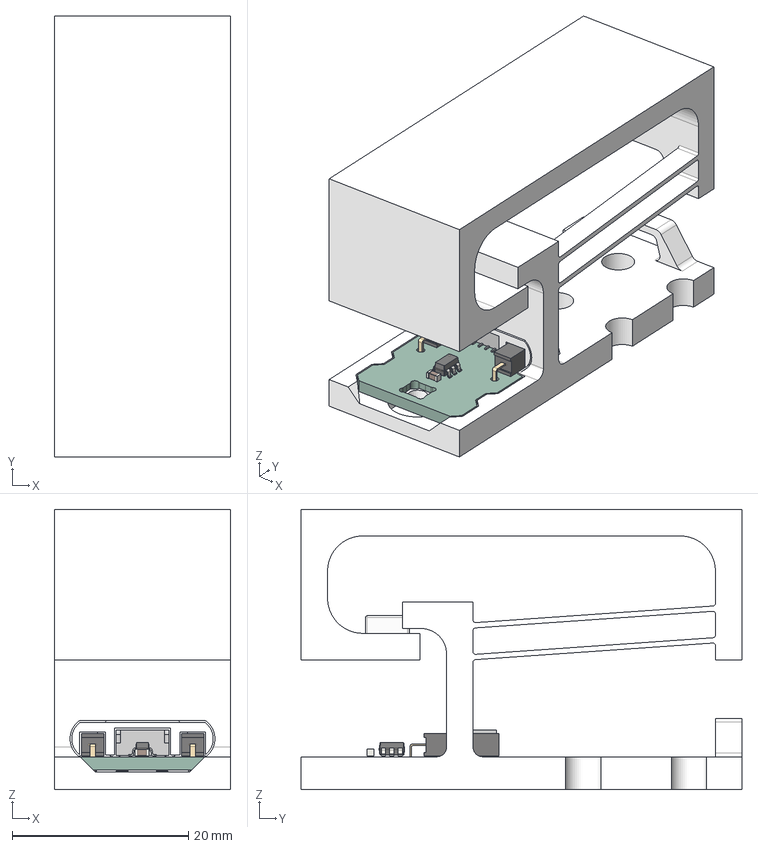
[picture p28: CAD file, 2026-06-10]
cad/mpe32sensor key.step
20.0 x 50.0 x 31.8 mm
PinSocket_1x01_P2.54mm_Horizontal_1 x 2
JST_SH_SM04B-SRSS-TB_1x04-1MP_P1.00mm_Horizontal_1
C_0603_1608Metric_1
SOT-23-6_1
Pin1
Pin2
Pin3
Pin4
mpe32sensor_PCB

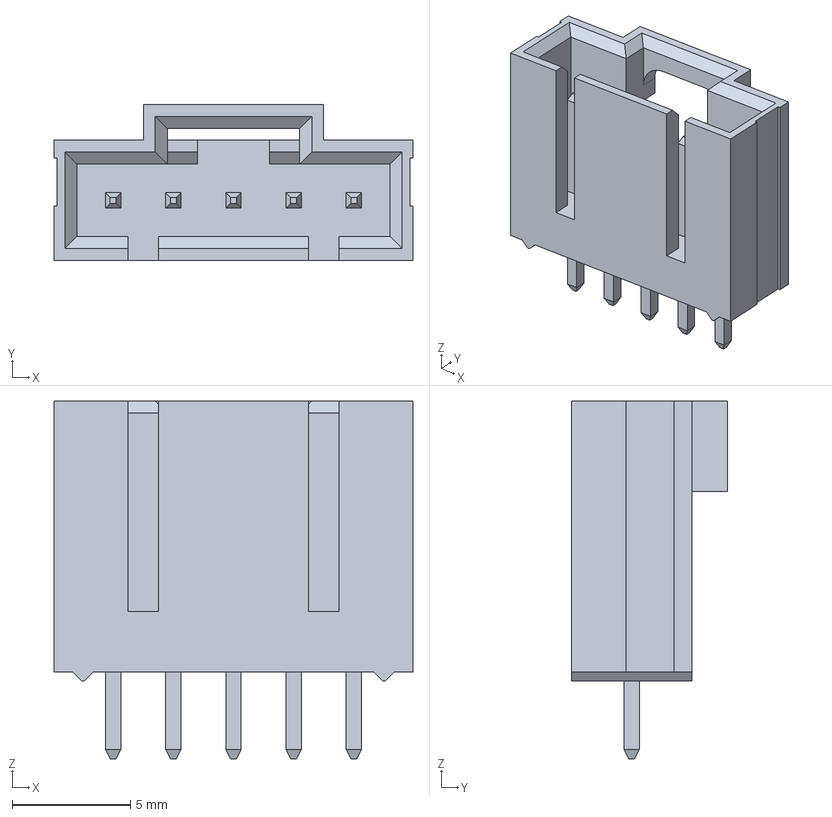
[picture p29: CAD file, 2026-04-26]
pcb/misc components/1x05 molex 1719710005.stp
15.2 x 6.60 x 15.1 mm

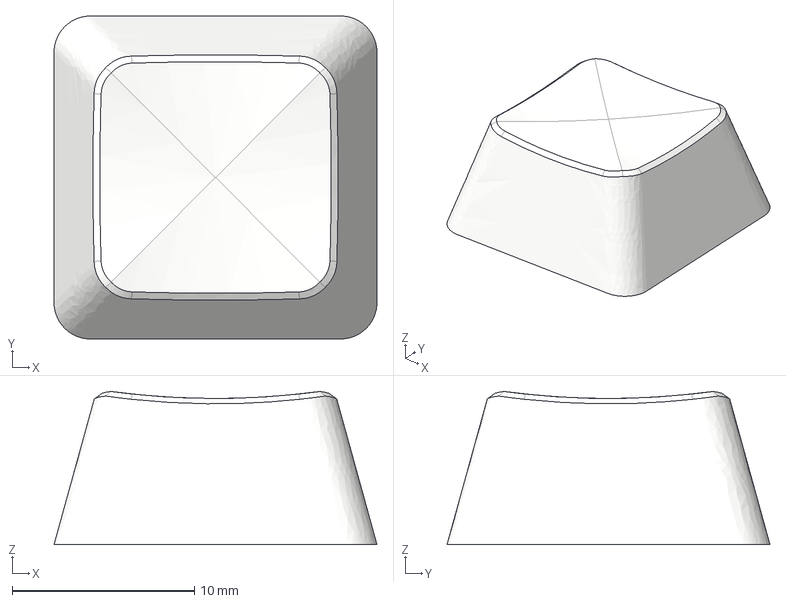
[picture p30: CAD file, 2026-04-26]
pcb/misc components/xdakeycap_v3.step
17.7 x 17.7 x 8.39 mm

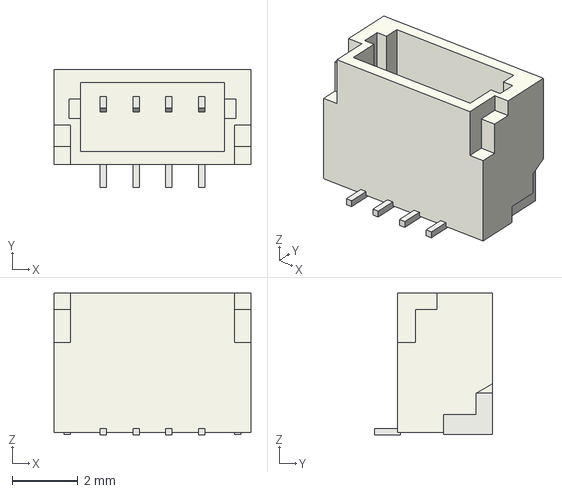
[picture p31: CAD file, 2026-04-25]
pcb/misc components/JST_SH_BM04B-SRSS-TB_1x04-1MP_P1.00mm_Vertical.step
6.00 x 3.60 x 4.32 mm

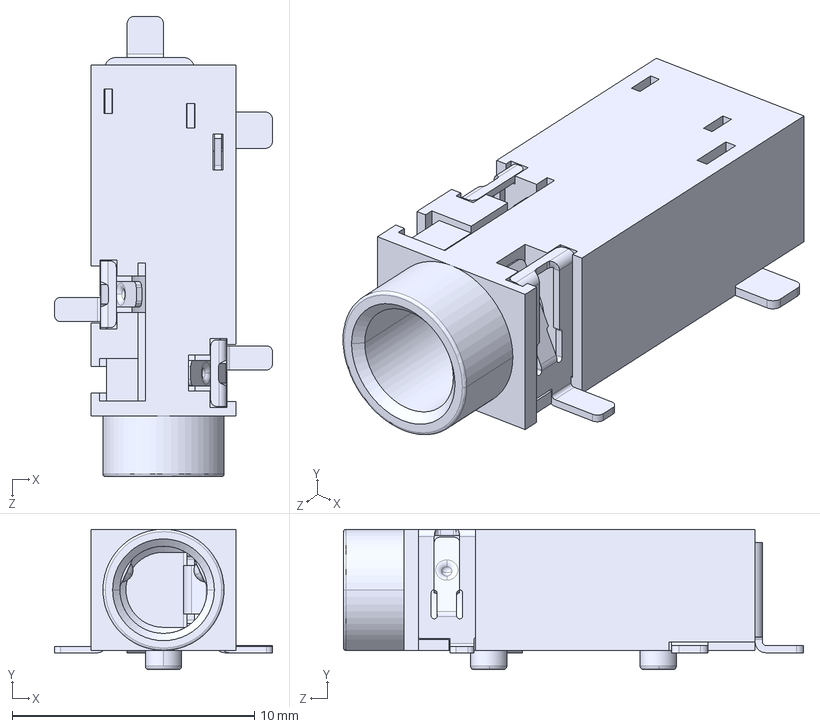
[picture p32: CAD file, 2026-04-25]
pcb/misc components/Same_Sky_SJ-3524-SMT-TR.step
9.00 x 5.80 x 19.0 mm

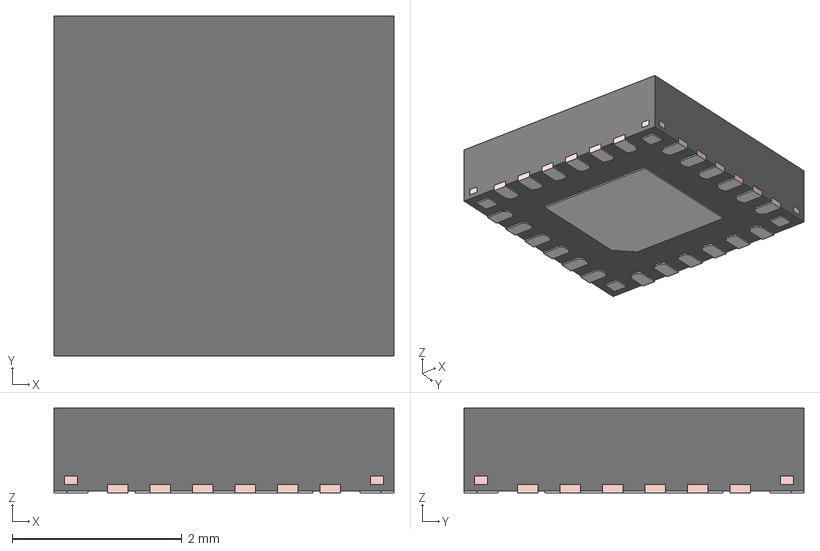
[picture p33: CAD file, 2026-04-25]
pcb/misc components/RGE0024R.stp
4.00 x 4.00 x 1.00 mm
FRAME

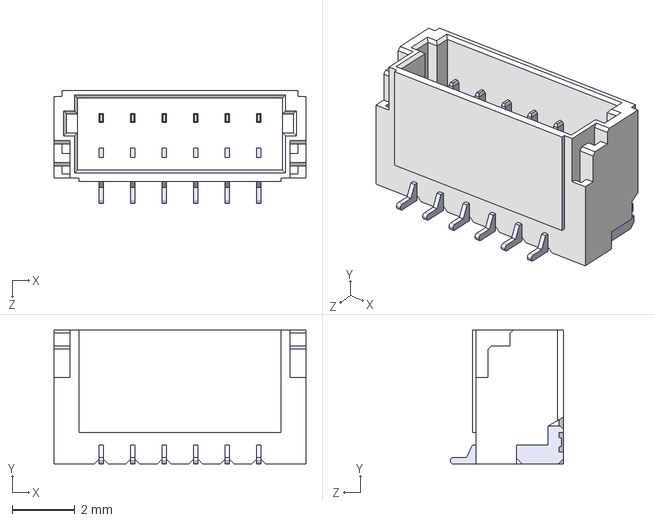
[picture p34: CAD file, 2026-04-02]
pcb/misc components/BM06B-SRSS-TB--3DModel-STEP-56544.STEP
8.00 x 4.25 x 3.60 mm

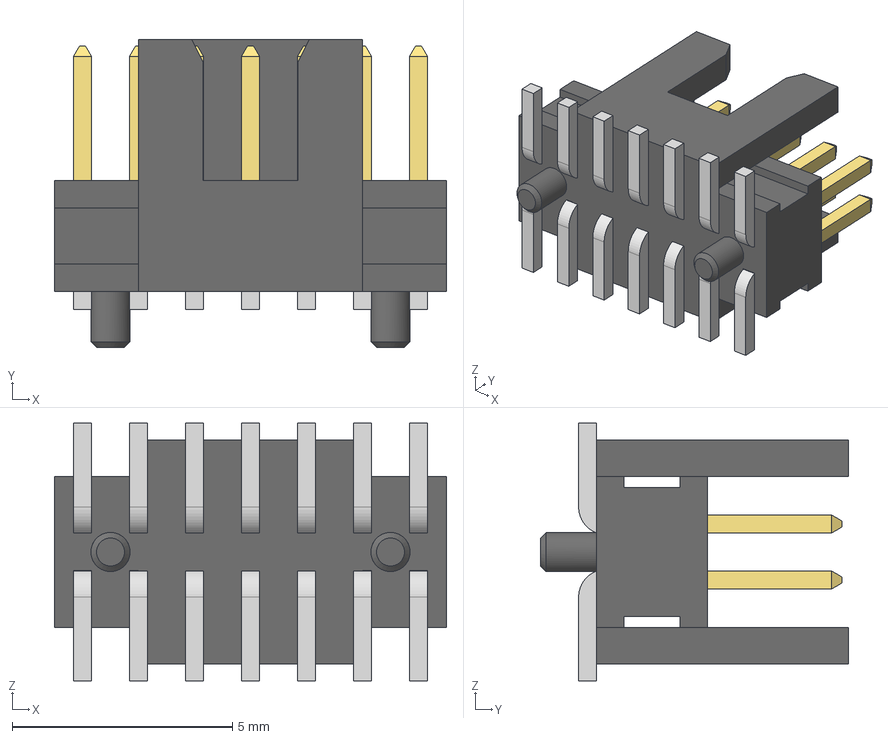
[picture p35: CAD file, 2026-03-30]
pcb/misc components/FTSH-107-01-L-DV-K-A.stp
8.89 x 6.98 x 5.84 mm
FTSH-107-01-L-DV-K-A_body
FTSH-107-01-L-DV-K-A_pins1
FTSH-107-01-L-DV-K-A_pins2

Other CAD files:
pcb/misc components/472192001.stp
cad/mpe32board.f3z
cad/mpe32sensor key small.f3d
cad/mpe32sensor key.f3d

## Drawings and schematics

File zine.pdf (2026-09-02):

### USB-C MIDI/Data Out

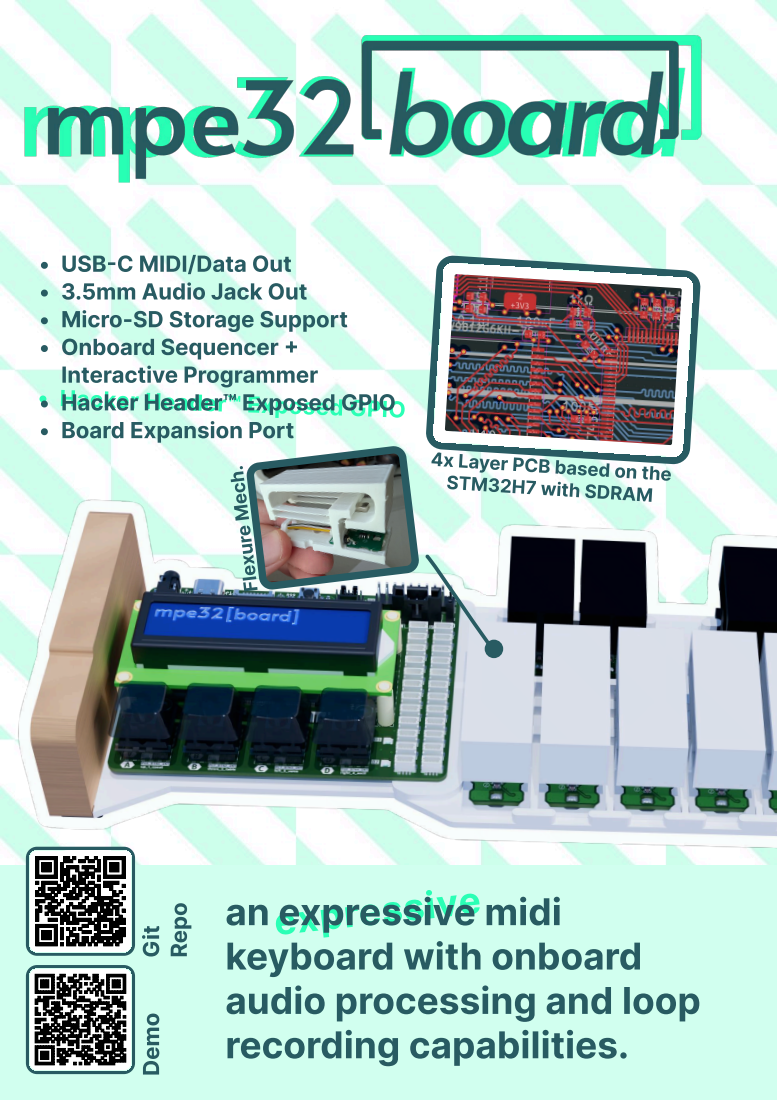
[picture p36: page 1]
Onboard Sequencer +; Interactive Programmer; Flexure Mech.; STM32H7 with SDRAM; Git; Demo; recording capabilities.

3.5mm Audio Jack Out

Micro-SD Storage Support

Hacker Header™ Exposed GPIO

Board Expansion Port

4x Layer PCB based on the

expressive an expressive midi

Repo
keyboard with onboard

audio processing and loop

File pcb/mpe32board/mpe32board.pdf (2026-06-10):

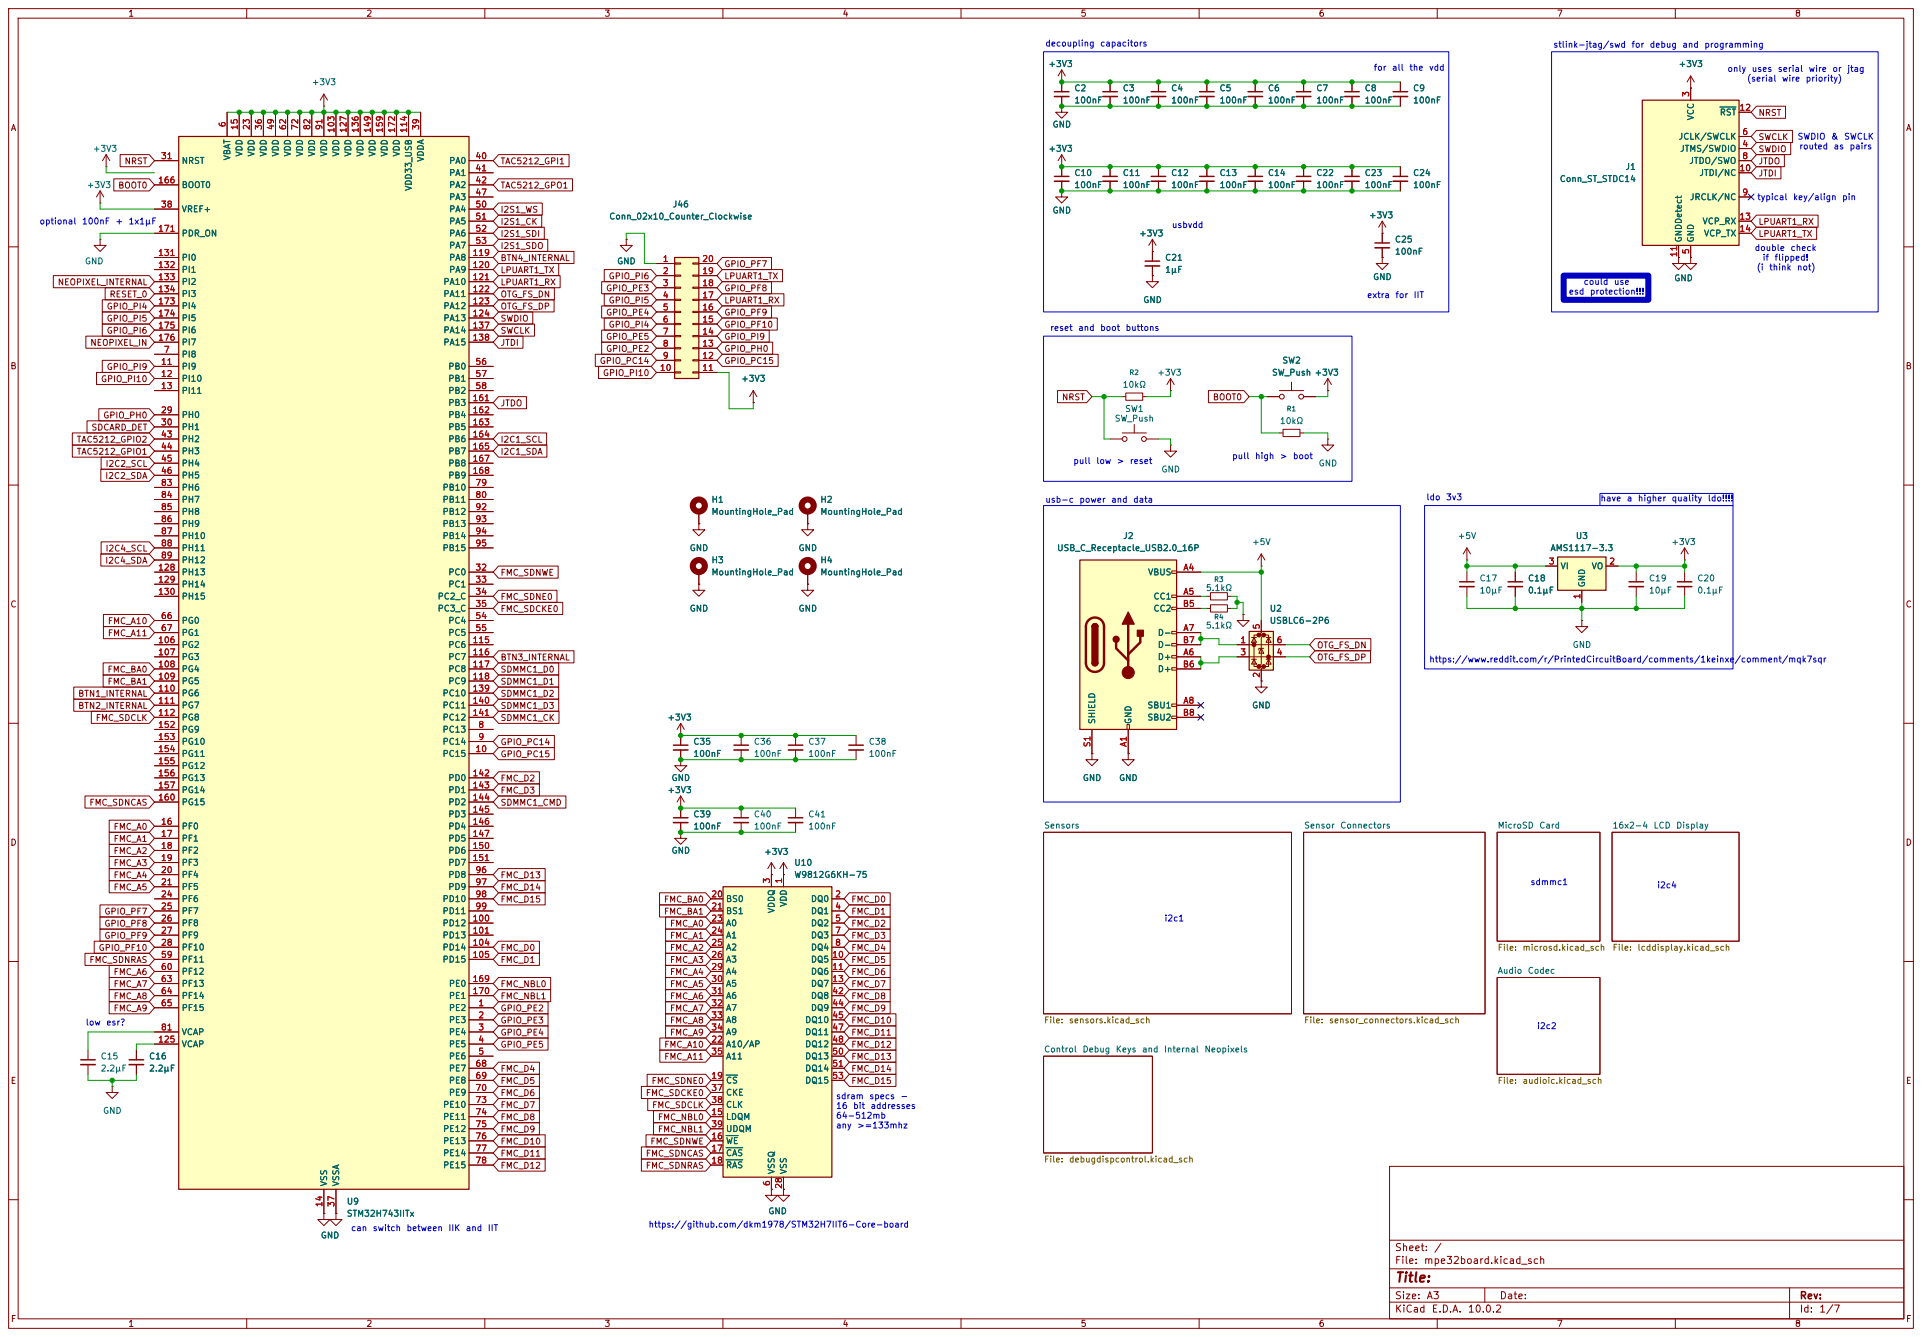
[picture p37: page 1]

stlink-jtag/swd for debug and programming
14 +3V3 GND

for all the vdd

only uses serial wire or jtag
(serial wire priority)

(i think not) have a higher quality ldo!!!! reset and boot buttons

GND
LDQM 15 WE 16 CAS 17 RAS 18 CS 19 BS0 20 BS1 21

can switch between IIK and IIT

https://github.com/dkm1978/STM32H7IIT6-Core-board

Size: A3 | Rev:
KiCad E.D.A. 10.0.2 | Id: 1/7 | F Date:

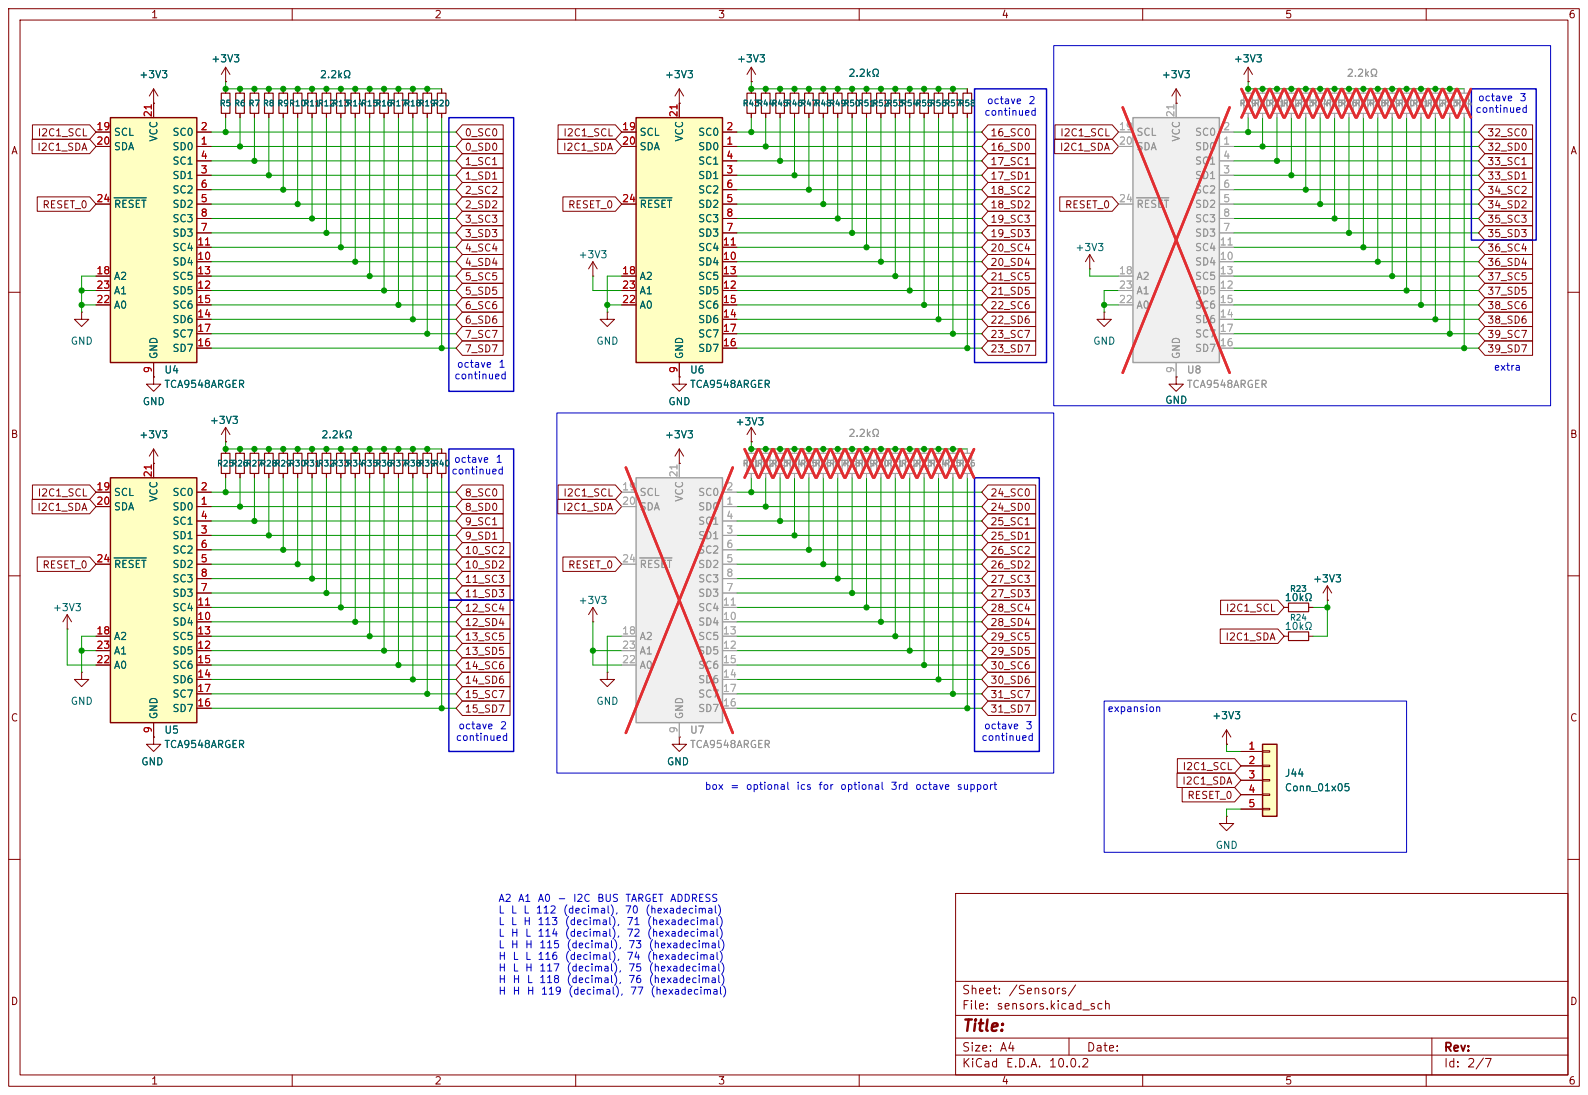
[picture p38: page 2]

box = optional ics for optional 3rd octave support octave 1
continued

L L L 112 (decimal), 70 (hexadecimal) L L H 113 (decimal), 71 (hexadecimal) L H L 114 (decimal), 72 (hexadecimal) L H H 115 (decimal), 73 (hexadecimal) H L L 116 (decimal), 74 (hexadecimal) H L H 117 (decimal), 75 (hexadecimal) H H L 118 (decimal), 76 (hexadecimal) H H H 119 (decimal), 77 (hexadecimal) octave 2

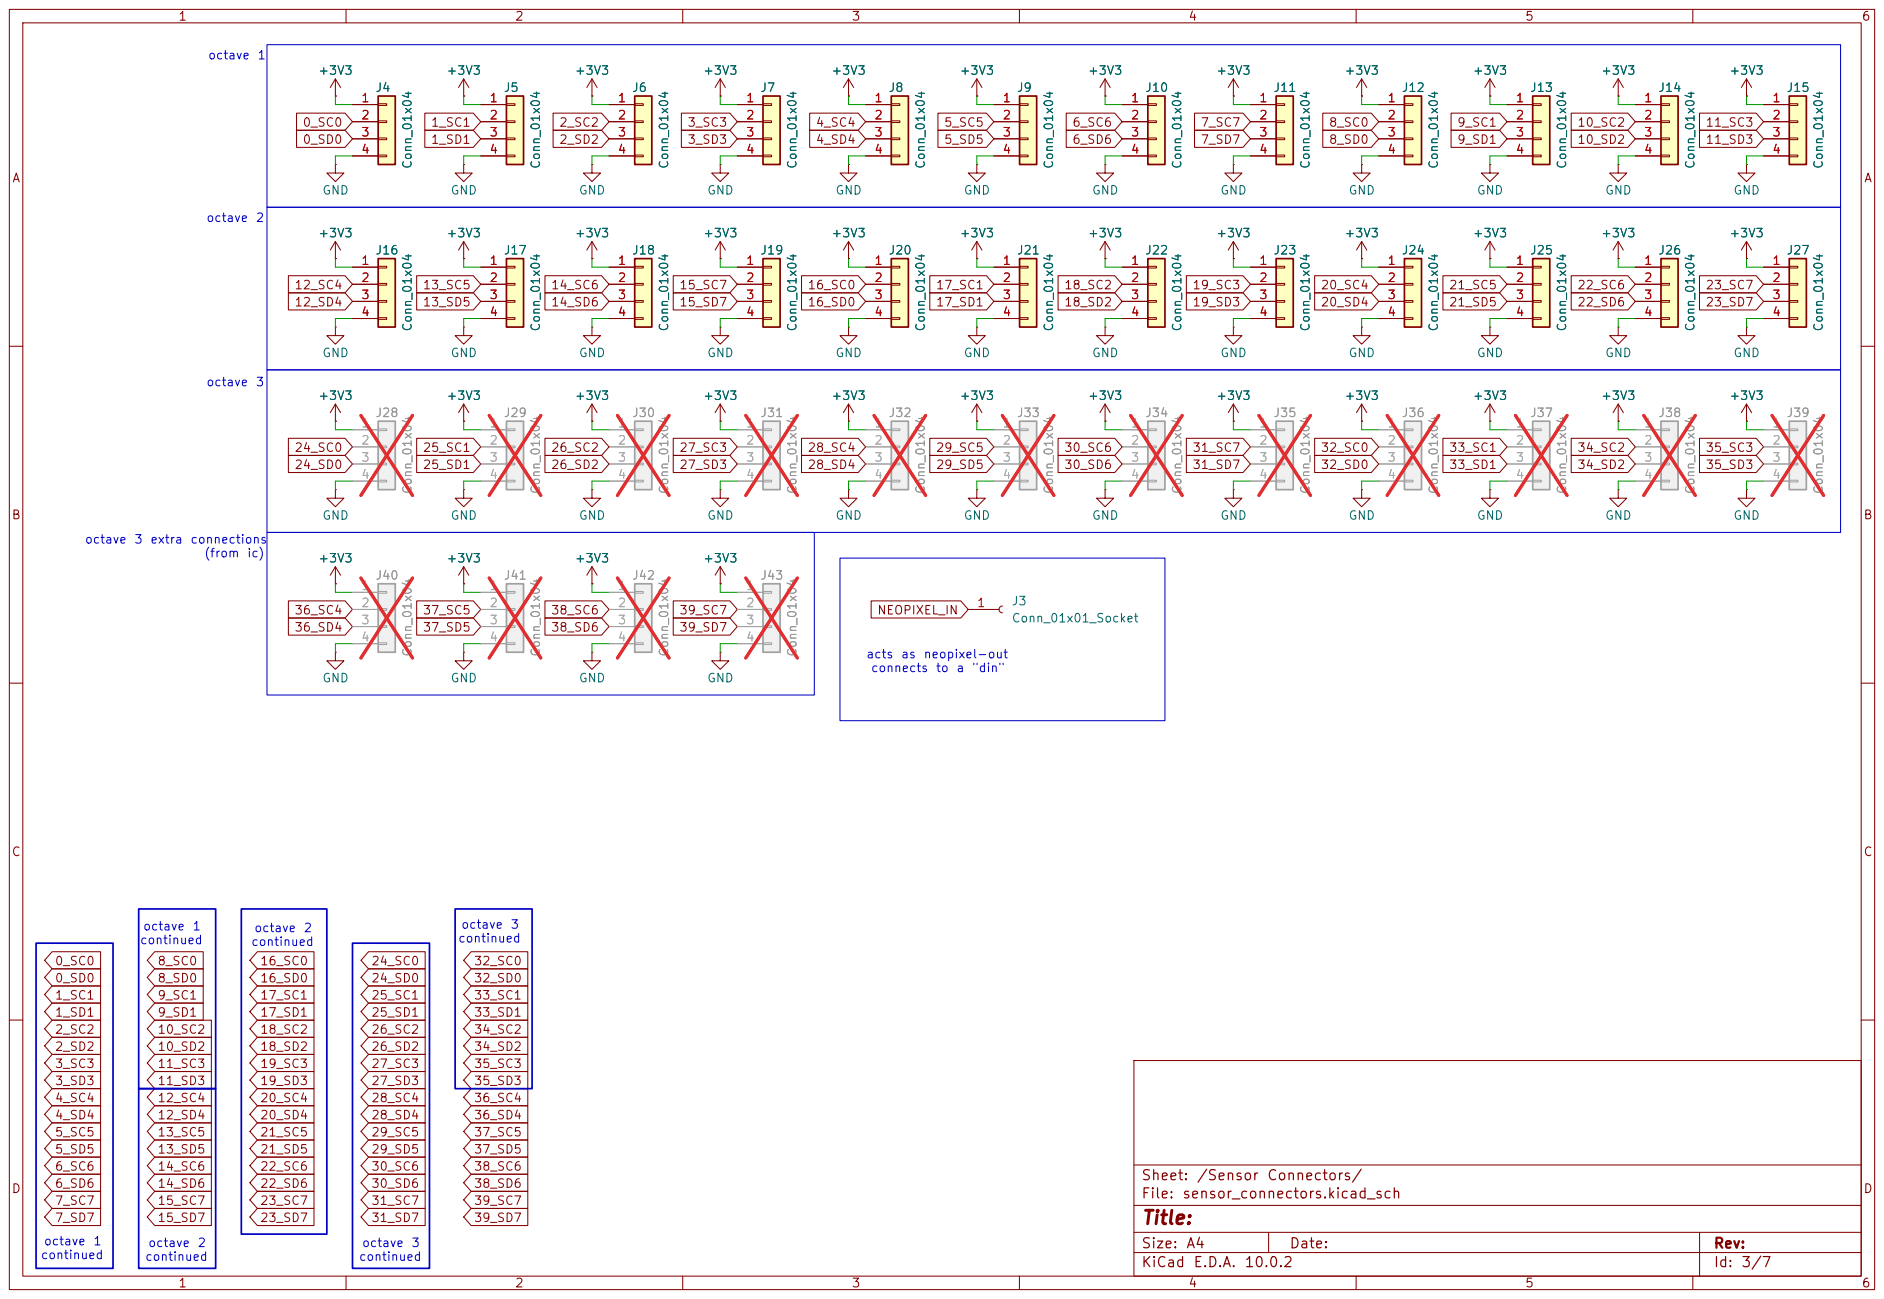
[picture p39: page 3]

acts as neopixel-out connects to a "din" octave 2

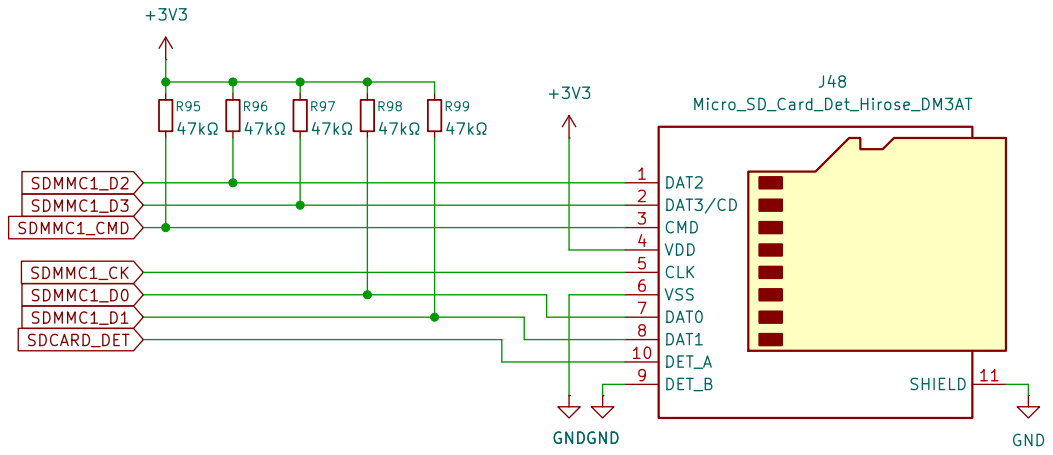
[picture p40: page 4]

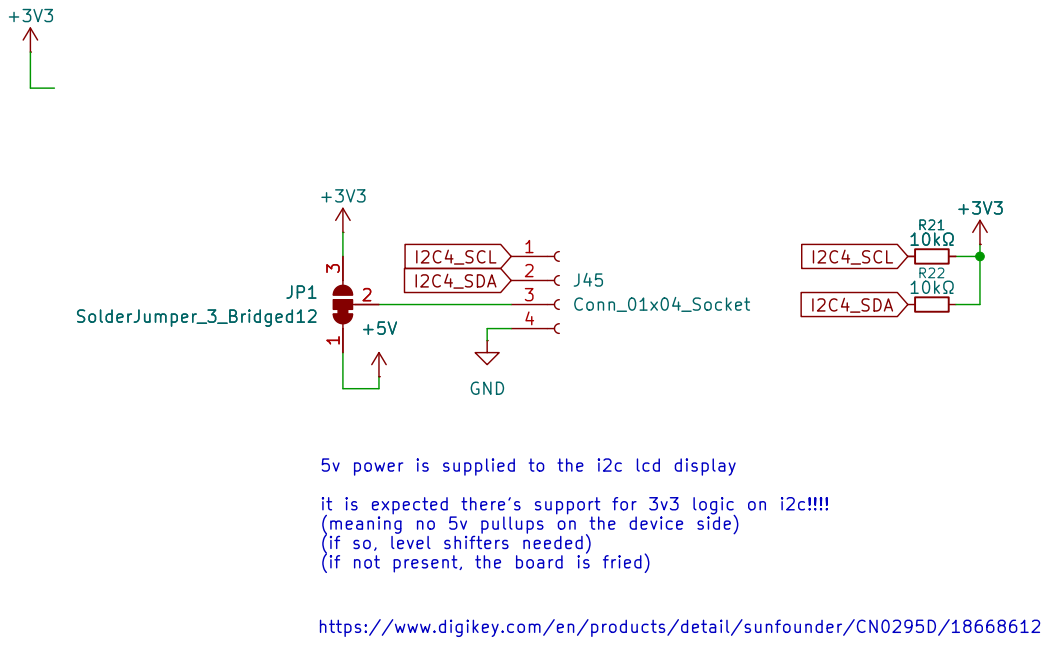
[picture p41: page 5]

I2C4_SCL 5v power is supplied to the i2c lcd display

it is expected there's support for 3v3 logic on i2c!!!! (meaning no 5v pullups on the device side)

(if so, level shifters needed) not present, the board is fried)

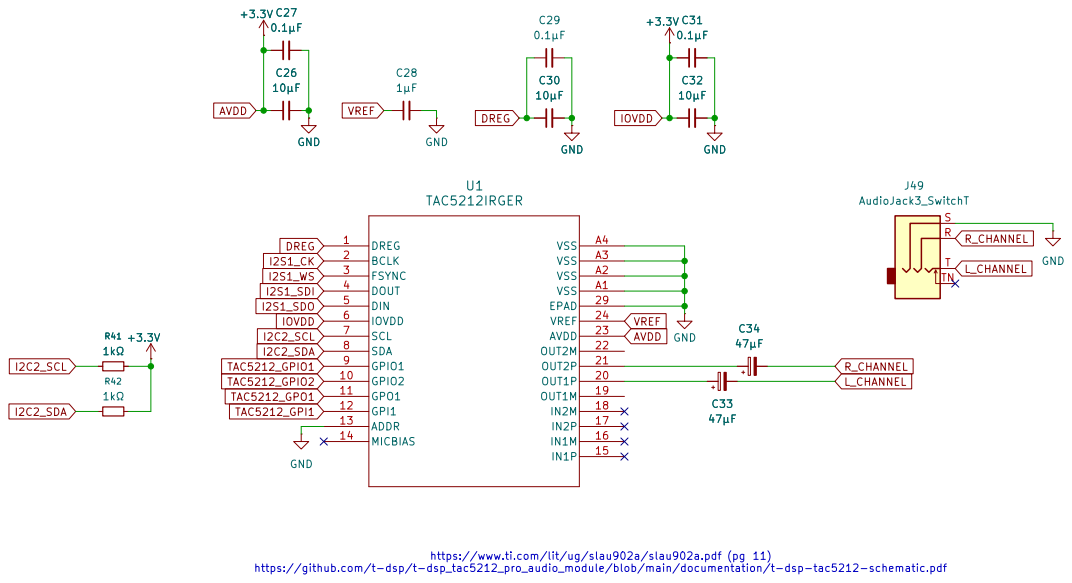
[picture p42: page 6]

https://github.com/t-dsp/t-dsp_tac5212_pro_audio_module/blob/main/documentation/t-dsp-tac5212-schematic.pdf GND

https://www.ti.com/lit/ug/slau902a/slau902a.pdf (pg 11)

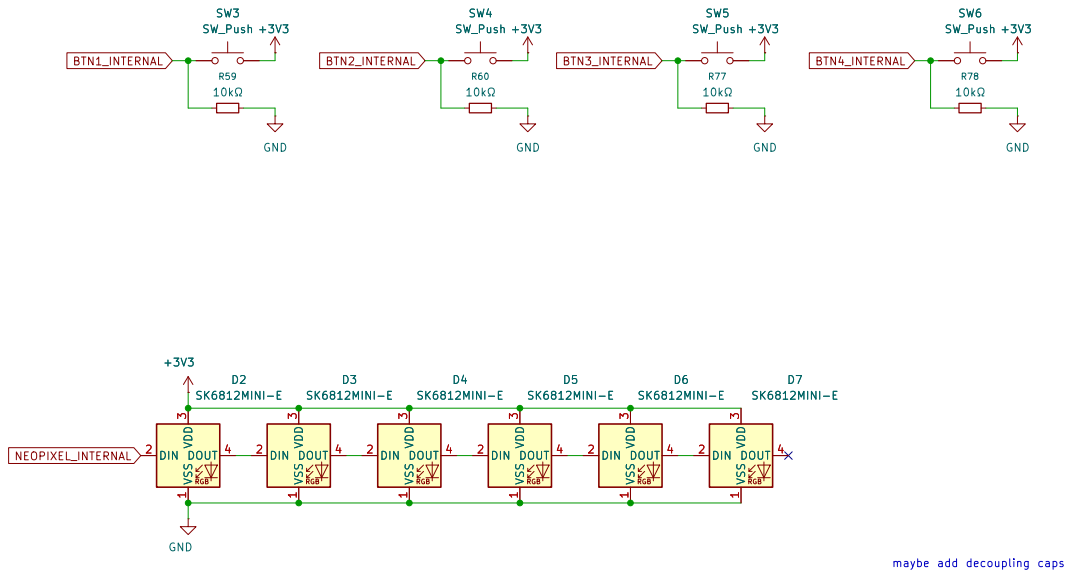
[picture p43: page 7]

Sheet: /Control Debug Keys and Internal Neopixels/
File: debugdispcontrol.kicad_sch
Title:

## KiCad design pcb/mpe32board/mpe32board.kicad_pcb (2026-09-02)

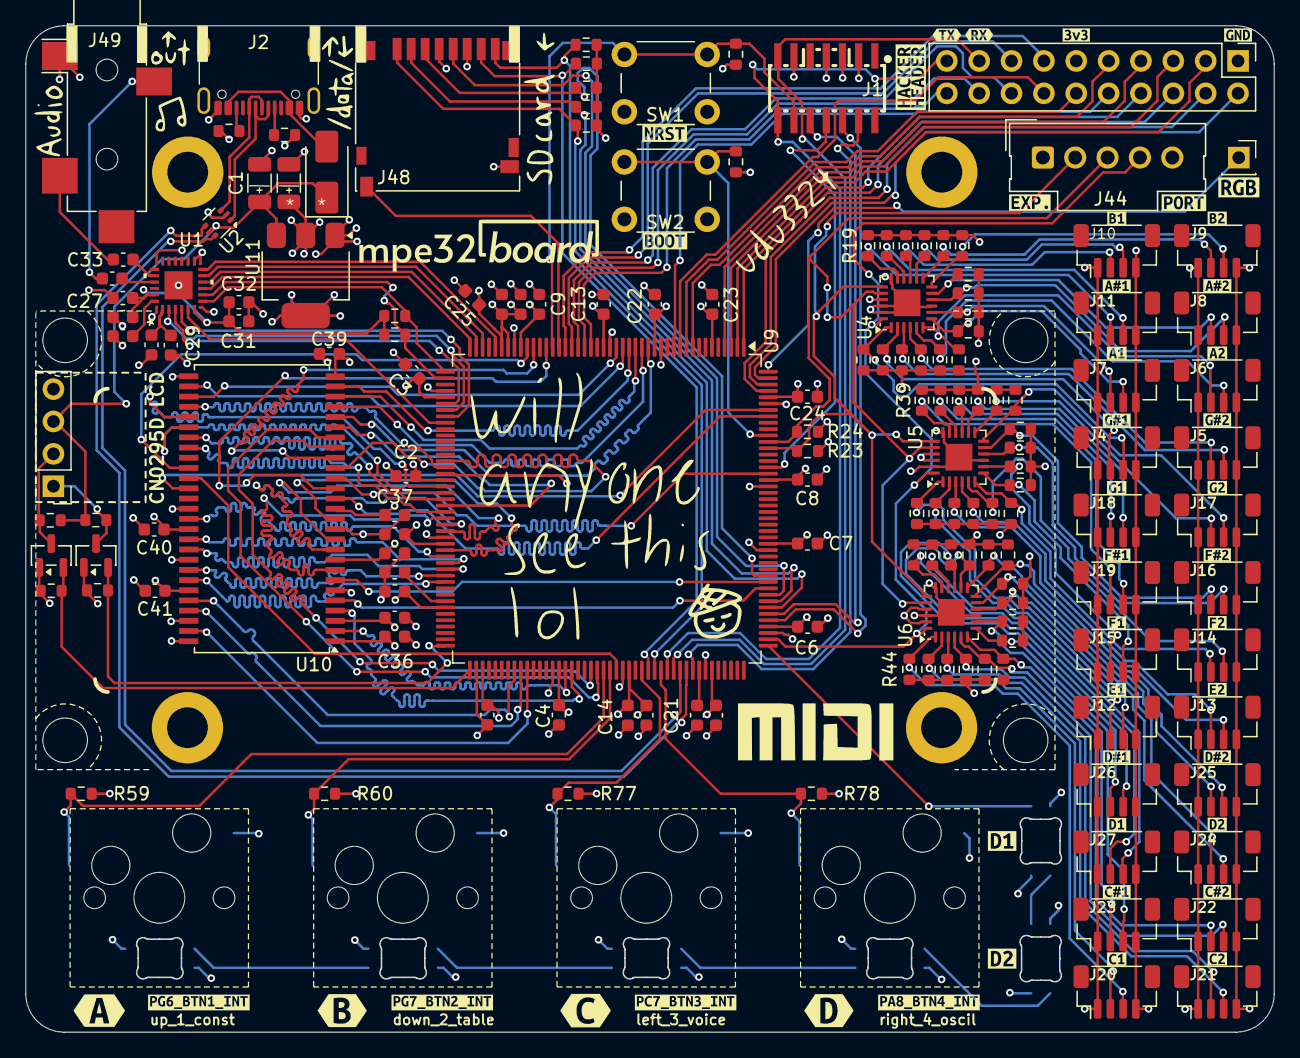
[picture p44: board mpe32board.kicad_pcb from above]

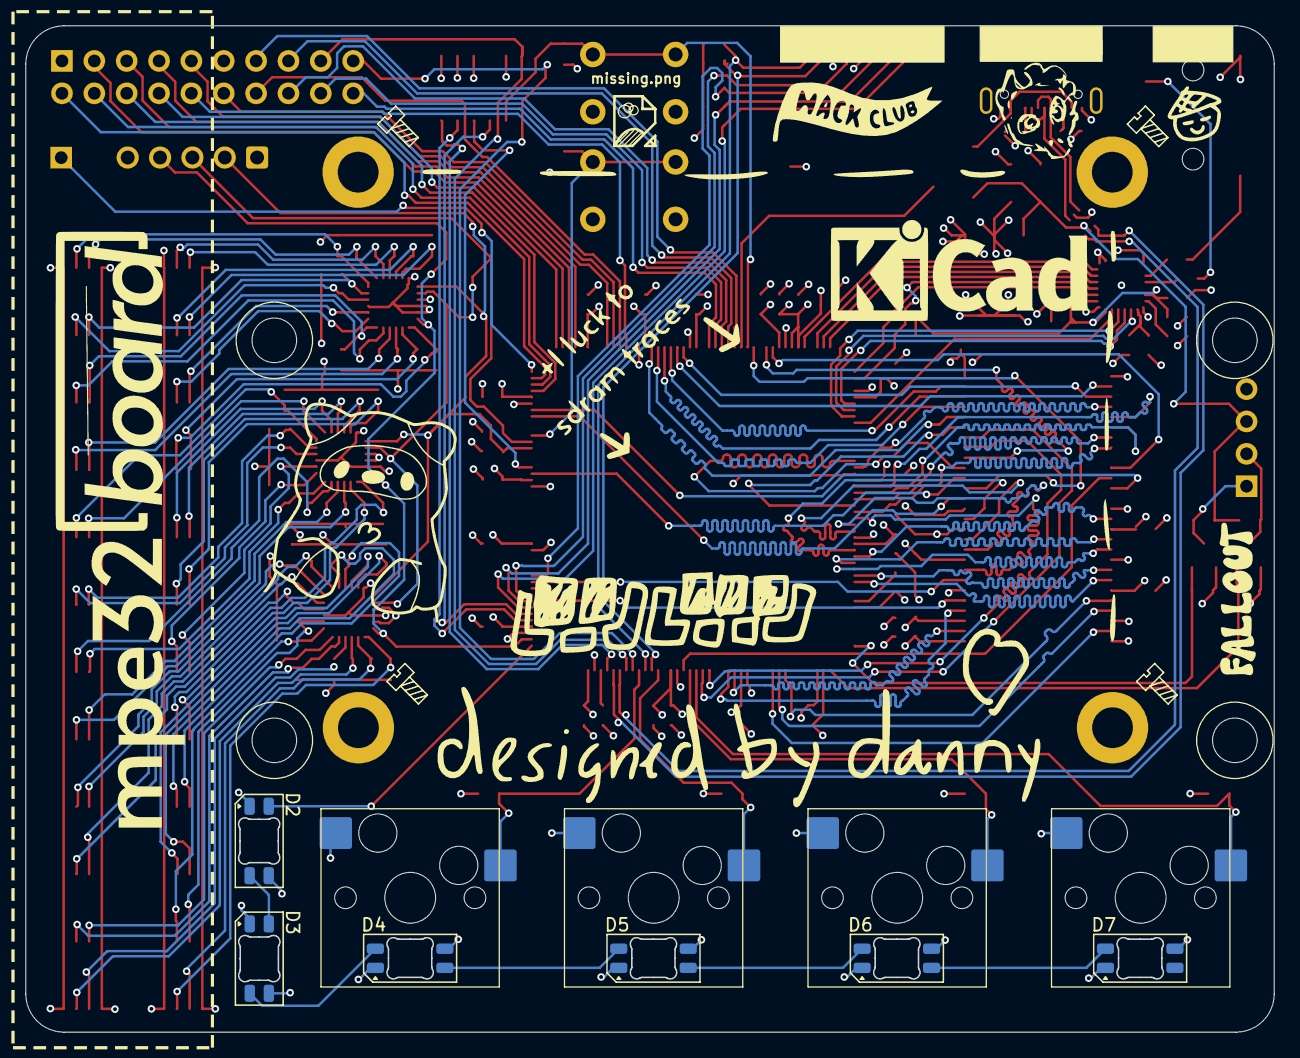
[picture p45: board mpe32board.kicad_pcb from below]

Board: 4 copper layers, 98.0 x 79.0 mm, 213 parts (10 on the bottom side), 164 nets.

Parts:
C1, C42: 10μF; C_1206_3216Metric
C2, C3, C4, C5, C6, C7, C8, C9, C10, C11, C12, C13, C14, C17, C22, C23, C24, C25, C35, C36, C37, C38, C39, C40, C41: 100nF; C_0603_1608Metric
C15, C16: 2.2μF; C_0603_1608Metric
C21, C28, C43: 1μF; C_0603_1608Metric
C26, C30, C32: 10μF; C_0603_1608Metric
C27, C29, C31: 0.1μF; C_0603_1608Metric
C33, C34: 47μF; C_0603_1608Metric
CN0295D LCD: CN0295D
D1: SS14; D_SMA
D2, D3, D4, D5, D6, D7: SK6812MINI-E; LED_SK6812MINI-E_3.2x2.8mm_P1.5mm_ReverseMount
H1, H2, H3, H4: MountingHole_Pad; MountingHole_3.2mm_M3_DIN965_Pad
J1: Conn_ST_STDC14; CONN-SMD_14P-P1.27_FTSH-107-01-F-DV-K-P-TR
J2: USB_C_Receptacle_USB2.0_16P; USB_C_Receptacle_GCT_USB4105-xx-A_16P_TopMnt_Horizontal
J3: Conn_01x01_Socket; PinSocket_1x01_P2.54mm_Vertical
J4, J5, J6, J7, J8, J9, J10, J11, J12, J13, J14, J15, J16, J17, J18, J19, J20, J21, J22, J23, J24, J25, J26, J27: Conn_01x04; JST_SH_BM04B-SRSS-TB_1x04-1MP_P1.00mm_Vertical
J44: Conn_01x05; Molex_SL_171971-0005_1x05_P2.54mm_Vertical
J45: Conn_01x04_Socket; PinHeader_1x04_P2.54mm_Vertical
J46: Conn_02x10_Counter_Clockwise; PinHeader_2x10_P2.54mm_Vertical
J48: Micro_SD_Card_Det_Hirose_DM3AT; microSD_HC_Hirose_DM3D-SF
J49: AudioJack3_SwitchT; Jack_3.5mm_CUI_SJ-3524-SMT_Horizontal
Q1, Q2: BSS138; SOT-23
R1, R2, R21, R22, R23, R24, R59, R60, R77, R78, R100, R101: 10kΩ; R_0603_1608Metric
R3, R4: 5.1kΩ; R_0603_1608Metric
R5, R6, R7, R8, R9, R10, R11, R12, R13, R14, R15, R16, R17, R18, R19, R20, R25, R26, R27, R28, R29, R30, R31, R32, R33, R34, R35, R36, R37, R38, R39, R40, R43, R44, R45, R46, R47, R48, R49, R50, R51, R52, R53, R54, R55, R56, R57, R58: 2.2kΩ; R_0603_1608Metric
R41, R42: 1kΩ; R_0603_1608Metric
R95, R96, R97, R98, R99: 47kΩ; R_0603_1608Metric
SW1, SW2: SW_Push; SW_PUSH_6mm
SW3, SW4, SW5, SW6: SW_Push; MX-Hotswap-1U
U1: TAC5212IRGER; VQFN24_RGE_CORNERPADS_TEX-L
U2: USBLC6-2P6; SOT-666
U4, U5, U6: TCA9548ARGER; Texas_RGE0024C_VQFN-24-1EP_4x4mm_P0.5mm_EP2.1x2.1mm
U9: STM32H743IITx; LQFP-176_24x24mm_P0.5mm
U10: W9812G6KH-75; TSOP-II-54_22.2x10.16mm_P0.8mm
U11: LM1117MP-3.3; SOT-223-3_TabPin2
kibuzzard-6A0A0E58: G***; kibuzzard-6A0A0E58
kibuzzard-6A0A0E61: G***; kibuzzard-6A0A0E61
kibuzzard-6A0A0E69: G***; kibuzzard-6A0A0E69
kibuzzard-6A0A0E77: G***; kibuzzard-6A0A0E77
kibuzzard-6A0A0F62: G***; kibuzzard-6A0A0F62
kibuzzard-6A0A0F87: G***; kibuzzard-6A0A0F87
kibuzzard-6A0A106B: G***; kibuzzard-6A0A106B
kibuzzard-6A0A124F: G***; kibuzzard-6A0A124F
kibuzzard-6A0A127D: G***; kibuzzard-6A0A127D
kibuzzard-6A0A1170: G***; kibuzzard-6A0A1170
kibuzzard-6A06ADD4: G***; kibuzzard-6A06ADD4
kibuzzard-6A06ADDB: G***; kibuzzard-6A06ADDB
kibuzzard-6A06ADE0: G***; kibuzzard-6A06ADE0
kibuzzard-6A06B0BE: G***; kibuzzard-6A06B0BE
kibuzzard-6A06B0F2: G***; kibuzzard-6A06B0F2
kibuzzard-6A06B37C: G***; kibuzzard-6A06B37C
kibuzzard-6A06B118: G***; kibuzzard-6A06B118
kibuzzard-6A06B135: G***; kibuzzard-6A06B135
kibuzzard-6A06B367: G***; kibuzzard-6A06B367
kibuzzard-6A0925D0: G***; kibuzzard-6A0925D0
kibuzzard-69FF71B5: G***; kibuzzard-69FF71B5
kibuzzard-69FF71C5: G***; kibuzzard-69FF71C5
kibuzzard-69FF71DB: G***; kibuzzard-69FF71DB
kibuzzard-69FF71E0: G***; kibuzzard-69FF71E0
kibuzzard-69FF72BF: G***; kibuzzard-69FF72BF
kibuzzard-69FF72C5: G***; kibuzzard-69FF72C5
kibuzzard-69FF72D8: G***; kibuzzard-69FF72D8
kibuzzard-69FF72DF: G***; kibuzzard-69FF72DF
kibuzzard-69FF72F7: G***; kibuzzard-69FF72F7
kibuzzard-69FF72FD: G***; kibuzzard-69FF72FD
kibuzzard-69FF73DD: G***; kibuzzard-69FF73DD
kibuzzard-69FF710F: G***; kibuzzard-69FF710F
kibuzzard-69FF713D: G***; kibuzzard-69FF713D
kibuzzard-69FF717D: G***; kibuzzard-69FF717D
kibuzzard-69FF719E: G***; kibuzzard-69FF719E
kibuzzard-69FF730D: G***; kibuzzard-69FF730D
kibuzzard-69FF732F: G***; kibuzzard-69FF732F
kibuzzard-69FF7163: G***; kibuzzard-69FF7163
kibuzzard-69FF7167: G***; kibuzzard-69FF7167
kibuzzard-69FF7176: G***; kibuzzard-69FF7176
kibuzzard-69FF7195: G***; kibuzzard-69FF7195
kibuzzard-69FF7319: G***; kibuzzard-69FF7319
kibuzzard-69FF7327: G***; kibuzzard-69FF7327
kibuzzard-69FF7392: G***; kibuzzard-69FF7392

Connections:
0_SC0: J4.2, R5.1, U4.2 (SC0)
0_SD0: J4.3, R6.1, U4.1 (SD0)
1_SC1: J5.2, R7.1, U4.4 (SC1)
1_SD1: J5.3, R8.1, U4.3 (SD1)
2_SC2: J6.2, R9.1, U4.6 (SC2)
2_SD2: J6.3, R10.1, U4.5 (SD2)
3_SC3: J7.2, R11.1, U4.8 (SC3)
3_SD3: J7.3, R12.1, U4.7 (SD3)
4_SC4: J8.2, R13.1, U4.11 (SC4)
4_SD4: J8.3, R14.1, U4.10 (SD4)
5_SC5: J9.2, R15.1, U4.13 (SC5)
5_SD5: J9.3, R16.1, U4.12 (SD5)
6_SC6: J10.2, R17.1, U4.15 (SC6)
6_SD6: J10.3, R18.1, U4.14 (SD6)
7_SC7: J11.2, R19.1, U4.17 (SC7)
7_SD7: J11.3, R20.1, U4.16 (SD7)
8_SC0: J12.2, R25.1, U5.2 (SC0)
8_SD0: J12.3, R26.1, U5.1 (SD0)
9_SC1: J13.2, R27.1, U5.4 (SC1)
9_SD1: J13.3, R28.1, U5.3 (SD1)
10_SC2: J14.2, R29.1, U5.6 (SC2)
10_SD2: J14.3, R30.1, U5.5 (SD2)
11_SC3: J15.2, R31.1, U5.8 (SC3)
11_SD3: J15.3, R32.1, U5.7 (SD3)
12_SC4: J16.2, R33.1, U5.11 (SC4)
12_SD4: J16.3, R34.1, U5.10 (SD4)
13_SC5: J17.2, R35.1, U5.13 (SC5)
13_SD5: J17.3, R36.1, U5.12 (SD5)
14_SC6: J18.2, R37.1, U5.15 (SC6)
14_SD6: J18.3, R38.1, U5.14 (SD6)
15_SC7: J19.2, R39.1, U5.17 (SC7)
15_SD7: J19.3, R40.1, U5.16 (SD7)
16_SC0: J20.2, R43.1, U6.2 (SC0)
16_SD0: J20.3, R44.1, U6.1 (SD0)
17_SC1: J21.2, R45.1, U6.4 (SC1)
17_SD1: J21.3, R46.1, U6.3 (SD1)
18_SC2: J22.2, R47.1, U6.6 (SC2)
18_SD2: J22.3, R48.1, U6.5 (SD2)
19_SC3: J23.2, R49.1, U6.8 (SC3)
19_SD3: J23.3, R50.1, U6.7 (SD3)
20_SC4: J24.2, R51.1, U6.11 (SC4)
20_SD4: J24.3, R52.1, U6.10 (SD4)
21_SC5: J25.2, R53.1, U6.13 (SC5)
21_SD5: J25.3, R54.1, U6.12 (SD5)
22_SC6: J26.2, R55.1, U6.15 (SC6)
22_SD6: J26.3, R56.1, U6.14 (SD6)
23_SC7: J27.2, R57.1, U6.17 (SC7)
23_SD7: J27.3, R58.1, U6.16 (SD7)
+3V3: C2.1, C3.1, C4.1, C5.1, C6.1, C7.1, C8.1, C9.1, C10.1, C11.1, C12.1, C13.1, C14.1, C17.1, C21.1, C22.1, C23.1, C24.1, C25.1, C35.1, C36.1, C37.1, C38.1, C39.1, C40.1, C41.1, C42.1, C43.1, D2.3 (VDD), D3.3 (VDD), D4.3 (VDD), D5.3 (VDD), D6.3 (VDD), D7.3 (VDD), J1.3 (VCC), J4.1, J5.1, J6.1, J7.1, J8.1, J9.1, J10.1, J11.1, J12.1, J13.1, J14.1, J15.1, J16.1, J17.1, J18.1, J19.1, J20.1, J21.1, J22.1, J23.1, J24.1, J25.1, J26.1, J27.1, J44.1, J46.11, J48.4 (VDD), Q1.1 (G), Q2.1 (G), R2.2, R5.2, R6.2, R7.2, R8.2, R9.2, R10.2, R11.2, R12.2, R13.2, R14.2, R15.2, R16.2, R17.2, R18.2, R19.2, R20.2, R21.1, R23.2, R24.2, R25.2, R26.2, R27.2, R28.2, R29.2, R30.2, R31.2, R32.2, R33.2, R34.2, R35.2, R36.2, R37.2, R38.2, R39.2, R40.2, R43.2, R44.2, R45.2, R46.2, R47.2, R48.2, R49.2, R50.2, R51.2, R52.2, R53.2, R54.2, R55.2, R56.2, R57.2, R58.2, R95.1, R96.1, R97.1, R98.1, R99.1, R100.1, SW2.2, SW3.2, SW4.2, SW5.2, SW6.2, U4.21 (VCC), U5.21 (VCC), U5.22 (A0), U6.21 (VCC), U6.23 (A1), U9.6 (VBAT), U9.15 (VDD), U9.23 (VDD), U9.36 (VDD), U9.38 (VREF+), U9.39 (VDDA), U9.49 (VDD), U9.62 (VDD), U9.72 (VDD), U9.82 (VDD), U9.91 (VDD), U9.103 (VDD), U9.114 (VDD33_USB), U9.127 (VDD), U9.136 (VDD), U9.149 (VDD), U9.159 (VDD), U9.172 (VDD), U10.1 (VDD), U10.3 (VDDQ), U10.9 (VDDQ), U10.14 (VDD), U10.27 (VDD), U10.43 (VDDQ), U10.49 (VDDQ), U11.2 (VO)
+5V: C1.1, D1.1 (K), J45.3, R22.2, R101.2, U2.5 (VBUS), U11.3 (VI)
AVDD: C26.1, C27.1, C31.1, C32.1, R41.2, R42.2, U1.6 (IOVDD), U1.23 (AVDD)
BOOT0: R1.1, SW2.1, U9.166 (BOOT0)
BTN1_INTERNAL: R59.1, SW3.1, U9.110 (PG6)
BTN2_INTERNAL: R60.1, SW4.1, U9.111 (PG7)
BTN3_INTERNAL: R77.1, SW5.1, U9.116 (PC7)
BTN4_INTERNAL: R78.1, SW6.1, U9.119 (PA8)
DREG: C29.1, C30.1, U1.1 (DREG)
FMC_A0: U9.16 (PF0), U10.23 (A0)
FMC_A1: U9.17 (PF1), U10.24 (A1)
FMC_A2: U9.18 (PF2), U10.25 (A2)
FMC_A3: U9.19 (PF3), U10.26 (A3)
FMC_A4: U9.20 (PF4), U10.29 (A4)
FMC_A5: U9.21 (PF5), U10.30 (A5)
FMC_A6: U9.60 (PF12), U10.31 (A6)
FMC_A7: U9.63 (PF13), U10.32 (A7)
FMC_A8: U9.64 (PF14), U10.33 (A8)
FMC_A9: U9.65 (PF15), U10.34 (A9)
FMC_A10: U9.66 (PG0), U10.22 (A10/AP)
FMC_A11: U9.67 (PG1), U10.35 (A11)
FMC_BA0: U9.108 (PG4), U10.20 (BS0)
FMC_BA1: U9.109 (PG5), U10.21 (BS1)
FMC_D0: U9.104 (PD14), U10.2 (DQ0)
FMC_D1: U9.105 (PD15), U10.4 (DQ1)
FMC_D2: U9.142 (PD0), U10.5 (DQ2)
FMC_D3: U9.143 (PD1), U10.7 (DQ3)
FMC_D4: U9.68 (PE7), U10.8 (DQ4)
FMC_D5: U9.69 (PE8), U10.10 (DQ5)
FMC_D6: U9.70 (PE9), U10.11 (DQ6)
FMC_D7: U9.73 (PE10), U10.13 (DQ7)
FMC_D8: U9.74 (PE11), U10.42 (DQ8)
FMC_D9: U9.75 (PE12), U10.44 (DQ9)
FMC_D10: U9.76 (PE13), U10.45 (DQ10)
FMC_D11: U9.77 (PE14), U10.47 (DQ11)
FMC_D12: U9.78 (PE15), U10.48 (DQ12)
FMC_D13: U9.96 (PD8), U10.50 (DQ13)
FMC_D14: U9.97 (PD9), U10.51 (DQ14)
FMC_D15: U9.98 (PD10), U10.53 (DQ15)
FMC_NBL0: U9.169 (PE0), U10.15 (LDQM)
FMC_NBL1: U9.170 (PE1), U10.39 (UDQM)
FMC_SDCKE0: U9.35 (PC3_C), U10.37 (CKE)
FMC_SDCLK: U9.112 (PG8), U10.38 (CLK)
FMC_SDNCAS: U9.160 (PG15), U10.17 (~CAS)
FMC_SDNE0: U9.34 (PC2_C), U10.19 (~CS)
FMC_SDNRAS: U9.59 (PF11), U10.18 (~RAS)
FMC_SDNWE: U9.32 (PC0), U10.16 (~WE)
GND: C1.2, C2.2, C3.2, C4.2, C5.2, C6.2, C7.2, C8.2, C9.2, C10.2, C11.2, C12.2, C13.2, C14.2, C15.2, C16.2, C17.2, C21.2, C22.2, C23.2, C24.2, C25.2, C26.2, C27.2, C28.2, C29.2, C30.2, C31.2, C32.2, C35.2, C36.2, C37.2, C38.2, C39.2, C40.2, C41.2, C42.2, C43.2, D2.1 (VSS), D3.1 (VSS), D4.1 (VSS), D5.1 (VSS), D6.1 (VSS), D7.1 (VSS), H1.1 (1_1), H2.1 (1_1), H3.1 (1_1), H4.1 (1_1), J1.5 (GND), J1.7 (GND), J1.11 (GNDDetect), J2.A1 (GND), J2.A12 (GND), J2.B1 (GND), J2.B12 (GND), J4.4, J5.4, J6.4, J7.4, J8.4, J9.4, J10.4, J11.4, J12.4, J13.4, J14.4, J15.4, J16.4, J17.4, J18.4, J19.4, J20.4, J21.4, J22.4, J23.4, J24.4, J25.4, J26.4, J27.4, J44.5, J45.4, J46.1, J48.6 (VSS), J48.9 (DET_B), J49.S, R1.2, R3.2, R4.2, R59.2, R60.2, R77.2, R78.2, SW1.2, U1.13 (ADDR), U1.29 (EPAD), U1.A1 (VSS), U1.A2 (VSS), U1.A3 (VSS), U1.A4 (VSS), U2.2 (GND), U4.9 (GND), U4.18 (A2), U4.22 (A0), U4.23 (A1), U5.9 (GND), U5.18 (A2), U5.23 (A1), U6.9 (GND), U6.18 (A2), U6.22 (A0), U9.14 (VSS), U9.22 (VSS), U9.37 (VSSA), U9.48 (VSS), U9.61 (VSS), U9.71 (VSS), U9.90 (VSS), U9.102 (VSS), U9.113 (VSS), U9.126 (VSS), U9.135 (VSS), U9.148 (VSS), U9.158 (VSS), U9.171 (PDR_ON), U10.6 (VSSQ), U10.12 (VSSQ), U10.28 (VSS), U10.41 (VSS), U10.46 (VSSQ), U10.52 (VSSQ), U10.54 (VSS), U11.1 (GND)
GPIO_PC14: J46.9, U9.9 (PC14)
GPIO_PC15: J46.12, U9.10 (PC15)
GPIO_PE2: J46.8, U9.1 (PE2)
GPIO_PE3: J46.3, U9.2 (PE3)
GPIO_PE4: J46.5, U9.3 (PE4)
GPIO_PE5: J46.7, U9.4 (PE5)
GPIO_PF7: J46.20, U9.25 (PF7)
GPIO_PF8: J46.18, U9.26 (PF8)
GPIO_PF9: J46.16, U9.27 (PF9)
GPIO_PF10: J46.15, U9.28 (PF10)
GPIO_PH0: J46.13, U9.29 (PH0)
GPIO_PI4: J46.6, U9.173 (PI4)
GPIO_PI5: J46.4, U9.174 (PI5)
GPIO_PI6: J46.2, U9.175 (PI6)
GPIO_PI9: J46.14, U9.11 (PI9)
GPIO_PI10: J46.10, U9.12 (PI10)
I2C1_SCL: J44.2, R23.1, U4.19 (SCL), U5.19 (SCL), U6.19 (SCL), U9.164 (PB6)
I2C1_SDA: J44.3, R24.1, U4.20 (SDA), U5.20 (SDA), U6.20 (SDA), U9.165 (PB7)
I2C2_SCL: R41.1, U1.7 (SCL), U9.45 (PH4)
I2C2_SDA: R42.1, U1.8 (SDA), U9.46 (PH5)
I2C4_SCL: Q1.2 (S), R21.2, U9.88 (PH11)
I2C4_SCL_5V: J45.1, Q1.3 (D), R22.1
I2C4_SDA: Q2.2 (S), R100.2, U9.89 (PH12)
I2C4_SDA_5V: J45.2, Q2.3 (D), R101.1
I2S1_CK: U1.2 (BCLK), U9.51 (PA5)
I2S1_SDI: U1.4 (DOUT), U9.52 (PA6)
I2S1_SDO: U1.5 (DIN), U9.53 (PA7)
I2S1_WS: U1.3 (FSYNC), U9.50 (PA4)
JTDI: J1.10 (JTDI/NC), U9.138 (PA15)
JTDO: J1.8 (JTDO/SWO), U9.161 (PB3)
LPUART1_RX: J1.13 (VCP_RX), J46.17, U9.121 (PA10)
LPUART1_TX: J1.14 (VCP_TX), J46.19, U9.120 (PA9)
L_CHANNEL: C33.2, J49.T
NEOPIXEL_IN: J3.1 (Pin_1_1), U9.176 (PI7)
NEOPIXEL_INTERNAL: D2.2 (DIN), U9.133 (PI2)
NRST: J1.12 (~RST), R2.1, SW1.1, U9.31 (NRST)
unnamed: C15.1, U9.81 (VCAP)
unnamed: C16.1, U9.125 (VCAP)
unnamed: D1.2 (A), J2.A4 (VBUS), J2.A9 (VBUS), J2.B4 (VBUS), J2.B9 (VBUS)
unnamed: D2.4 (DOUT), D3.2 (DIN)
unnamed: D3.4 (DOUT), D4.2 (DIN)
unnamed: D4.4 (DOUT), D5.2 (DIN)
unnamed: D5.4 (DOUT), D6.2 (DIN)
unnamed: D6.4 (DOUT), D7.2 (DIN)
unnamed: J2.A5 (CC1), R3.1
unnamed: J2.B5 (CC2), R4.1
unnamed: J2.A6 (D+), J2.B6 (D+), U2.3 (I/O2)
unnamed: J2.A7 (D-), J2.B7 (D-), U2.1 (I/O1)
unnamed: C33.1, U1.20 (OUT1P)
unnamed: C34.1, U1.21 (OUT2P)
OTG_FS_DN: U2.6 (I/O1), U9.122 (PA11)
OTG_FS_DP: U2.4 (I/O2), U9.123 (PA12)
RESET_0: J44.4, U4.24 (~RESET), U5.24 (~RESET), U6.24 (~RESET), U9.134 (PI3)
R_CHANNEL: C34.2, J49.R
SDCARD_DET: J48.10 (DET_A), U9.30 (PH1)
SDMMC1_CK: J48.5 (CLK), U9.141 (PC12)
SDMMC1_CMD: J48.3 (CMD), R95.2, U9.144 (PD2)
SDMMC1_D0: J48.7 (DAT0), R98.2, U9.117 (PC8)
SDMMC1_D1: J48.8 (DAT1), R99.2, U9.118 (PC9)
SDMMC1_D2: J48.1 (DAT2), R96.2, U9.139 (PC10)
SDMMC1_D3: J48.2 (DAT3/CD), R97.2, U9.140 (PC11)
SWCLK: J1.6 (JCLK/SWCLK), U9.137 (PA14)
SWDIO: J1.4 (JTMS/SWDIO), U9.124 (PA13)
TAC5212_GPI1: U1.12 (GPI1), U9.40 (PA0)
TAC5212_GPIO1: U1.9 (GPIO1), U9.44 (PH3)
TAC5212_GPIO2: U1.10 (GPIO2), U9.43 (PH2)
TAC5212_GPO1: U1.11 (GPO1), U9.42 (PA2)
VREF: C28.1, U1.24 (VREF)

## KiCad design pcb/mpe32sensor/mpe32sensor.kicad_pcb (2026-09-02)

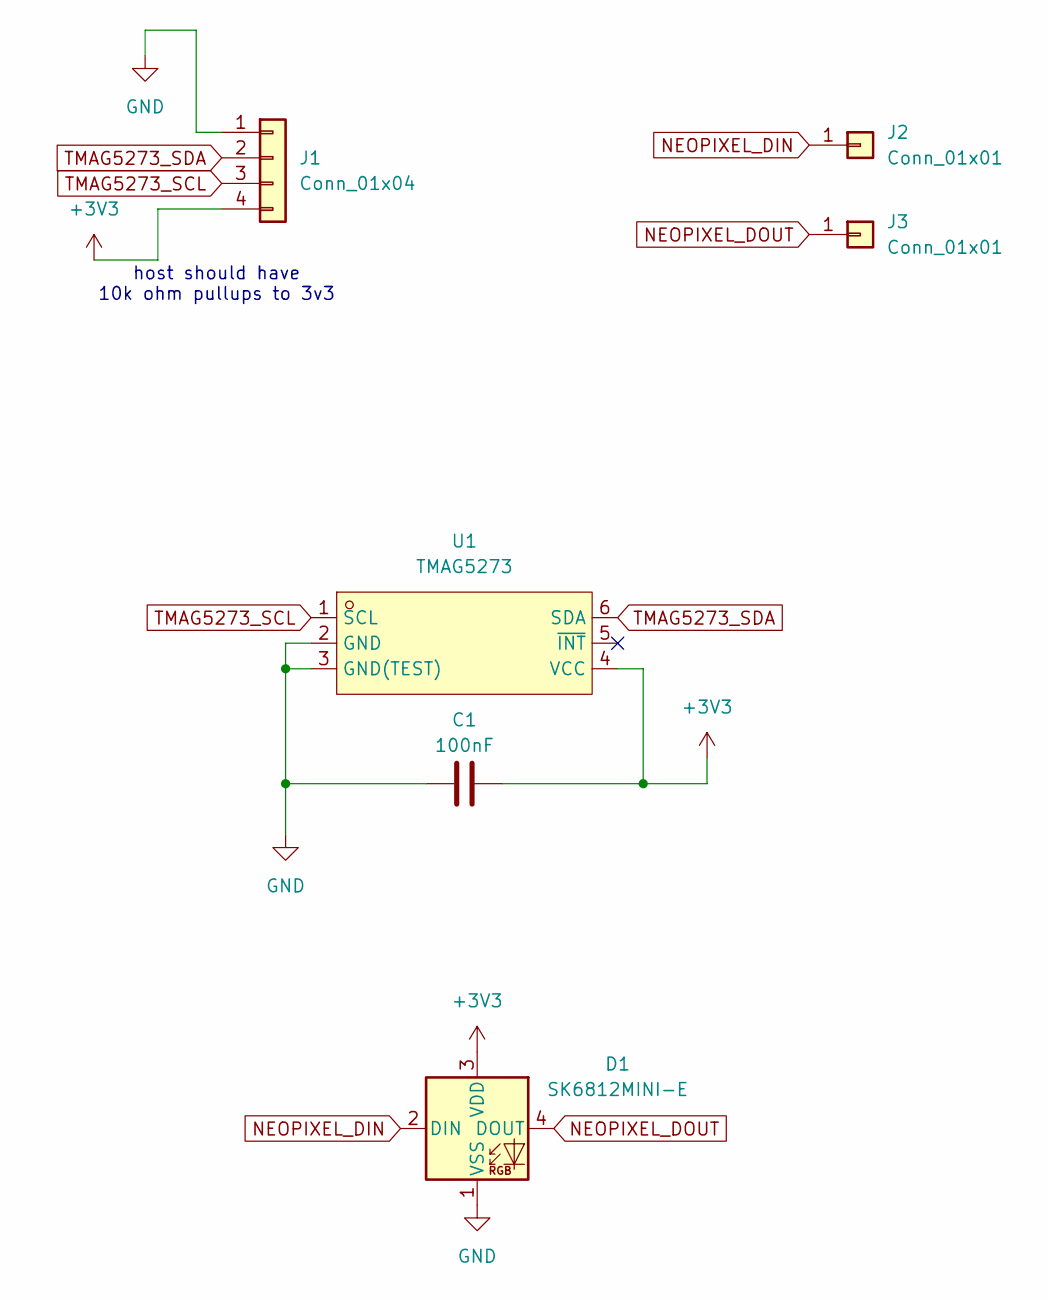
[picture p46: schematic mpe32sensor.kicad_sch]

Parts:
C1: 100nF; C_0603_1608Metric; MPN 100nF 0603 X7R
D1: SK6812MINI-E; LED_SK6812MINI-E_3.2x2.8mm_P1.5mm_ReverseMount; MPN SK6812MINI-E OPSCO Optoelectronics C514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
J1: Conn_01x04; JST_SH_SM04B-SRSS-TB_1x04-1MP_P1.00mm_Horizontal; MPN SM04B-SRSS-TB
J2, J3: Conn_01x01; PinSocket_1x01_P2.54mm_Horizontal; MPN DNP
U1: TMAG5273; SOT-23-6; MPN TMAG5273A1; LCSC Part C3716049

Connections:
+3V3: C1.2, D1.3 (VDD), J1.4, U1.4 (VCC)
GND: C1.1, D1.1 (VSS), J1.1, U1.2 (GND), U1.3 (GND(TEST))
NEOPIXEL_DIN: D1.2 (DIN), J2.1 (Pin_1_1)
NEOPIXEL_DOUT: D1.4 (DOUT), J3.1 (Pin_1_1)
TMAG5273_SCL: J1.3, U1.1 (SCL)
TMAG5273_SDA: J1.2, U1.6 (SDA)

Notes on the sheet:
host should have 10k ohm pullups to 3v3

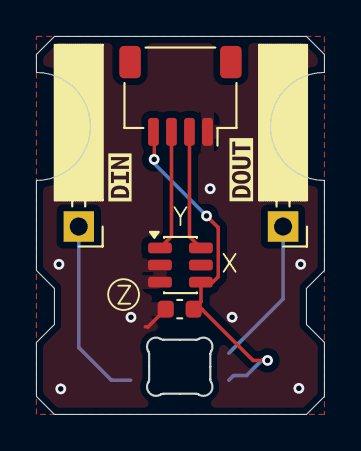
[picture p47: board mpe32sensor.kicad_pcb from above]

Board: 2 copper layers, 16.0 x 21.0 mm, 8 parts (1 on the bottom side), 6 nets.

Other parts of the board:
kibuzzard-6A0A33B3: G***; kibuzzard-6A0A33B3
kibuzzard-6A0A338E: G***; kibuzzard-6A0A338E

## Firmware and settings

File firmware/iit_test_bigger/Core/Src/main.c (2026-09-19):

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
/* Includes ------------------------------------------------------------------*/
#include "main.h"

/* USER CODE BEGIN Includes */

#include <stdint.h>
#include <stdio.h>

#include "stm32h7xx_hal.h"
#include "stm32h7xx_hal_gpio.h"
#include "tusb.h" 
#include "i2c-mux.h"
#include "neopixel32.h"
#include "i2clcd.h"
#include "helper.h"
#include "lcd-helper.h"
#include "TMAG5273.h"

/* USER CODE END Includes */


I2C_HandleTypeDef hi2c1;
I2C_HandleTypeDef hi2c2;
I2C_HandleTypeDef hi2c4;

I2S_HandleTypeDef hi2s1;

UART_HandleTypeDef hlpuart1;

SD_HandleTypeDef hsd1;

TIM_HandleTypeDef htim8;
DMA_HandleTypeDef hdma_tim8_ch4;

PCD_HandleTypeDef hpcd_USB_OTG_FS;

SDRAM_HandleTypeDef hsdram1;

/* USER CODE BEGIN PV */
i2c_mux_t tca_mux_1 = {
  .hi2c = &hi2c1,
	.rst_port = GPIOI,
	.rst_pin = GPIO_PIN_3,
	.addr_offset = 0
};

i2c_mux_t tca_mux_2 = {
  .hi2c = &hi2c1,
	.rst_port = GPIOI,
	.rst_pin = GPIO_PIN_3,
	.addr_offset = 1
};

i2c_mux_t tca_mux_3 = {
  .hi2c = &hi2c1,
	.rst_port = GPIOI,
	.rst_pin = GPIO_PIN_3,
	.addr_offset = 2
};

NP32_Instance_t neopixel_instance_internal;

NP32_RGB_t color_black = {0, 0, 0};
NP32_RGB_t color_red = {10, 0, 0};
NP32_RGB_t color_blue = {0, 0, 10};

I2C_LCD_HandleTypeDef lcd;




TMAG5273_Handle_t tmag_handles[25];
bool runOneshot = true;
/* USER CODE END PV */

void SystemClock_Config(void);
static void MPU_Config(void);
static void MX_GPIO_Init(void);
static void MX_DMA_Init(void);
static void MX_FMC_Init(void);
static void MX_I2C1_Init(void);
static void MX_I2C2_Init(void);
static void MX_I2C4_Init(void);
static void MX_SDMMC1_SD_Init(void);
static void MX_I2S1_Init(void);
static void MX_LPUART1_UART_Init(void);
static void MX_TIM8_Init(void);
static void MX_USB_OTG_FS_PCD_Init(void);
/* USER CODE BEGIN 0 */

//ty https://github.com/ElisaCastellari/prova-cps-progettob
int8_t Start_LED_DMA(uint16_t *buf, uint16_t len) {
  HAL_StatusTypeDef status = HAL_TIM_PWM_Start_DMA(&htim8, TIM_CHANNEL_4, (uint32_t *)buf, len);
  return status == HAL_OK ? 0 : -1;
}

void HAL_TIM_PWM_PulseFinishedCallback(TIM_HandleTypeDef *htim) {
  if (htim->Instance == TIM8) {
    // Avvisa la libreria che il buffer è libero
    NP32_DMAComplete_Callback(&neopixel_instance_internal);
    // Ferma il PWM
    HAL_TIM_PWM_Stop_DMA(&htim8, TIM_CHANNEL_4);
  }
}

/* USER CODE END 0 */

/**
  * @brief  The application entry point.
  * @retval int
  */
int main(void)
{

  /* MPU Configuration--------------------------------------------------------*/
  MPU_Config();

  /* MCU Configuration--------------------------------------------------------*/

  /* Reset of all peripherals, Initializes the Flash interface and the Systick. */
  HAL_Init();

  /* Configure the system clock */
  SystemClock_Config();

  /* Initialize all configured peripherals */
  MX_GPIO_Init();
  MX_DMA_Init();
  MX_FMC_Init();
  MX_I2C1_Init();
  MX_I2C2_Init();
  MX_I2C4_Init();
  MX_SDMMC1_SD_Init();
  MX_I2S1_Init();
  MX_LPUART1_UART_Init();
  MX_TIM8_Init();
  MX_USB_OTG_FS_PCD_Init();
  /* USER CODE BEGIN 2 */

  debugtalk("hello world\r\n");

  // init neopixels --------------------------------------------------------------------------------------------------------------------
  neopixel_instance_internal.LED_Count = 6;
  neopixel_instance_internal.StartDMA_Call = Start_LED_DMA;

  if (NP32_Init(&neopixel_instance_internal) != 0) {
    // error initializing!@!!
    debugtalk("bad0\r\n");
    Error_Handler();
  }

  NP32_SetAllLEDs_RGB(&neopixel_instance_internal, color_black);
  NP32_Update(&neopixel_instance_internal);
  
  // init i2c lcd display --------------------------------------------------------------------------------------------------------------
  //scan all addresses on i2c as some lcd modules use random
  uint16_t lcd_address = probe_lcd_i2c_addr();

  if (HAL_I2C_IsDeviceReady(&hi2c4, lcd_address, 3, 100) != HAL_OK) {
    debugtalk("LCD not found\r\n");
  } else {
    debugtalk("LCD found\r\n");
  }

  lcd.hi2c = &hi2c4;
  lcd.address = (uint8_t)lcd_address;
  lcd_init(&lcd);
  lcd_clear(&lcd);

  lcd_puts(&lcd, "welcome to");
  lcd_gotoxy(&lcd, 0, 1);
  lcd_puts(&lcd, "mpe32board.");


  // init i2c muxes 4 sensors ----------------------------------------------------------------------------------------------------------
  // set mp-reset on the i2c mux to be high as it is active-low reset input
	HAL_GPIO_WritePin(GPIOI, GPIO_PIN_3, GPIO_PIN_SET);

  // disable all i2c channels for a clean slate bruh
	if (i2c_mux_reset(&tca_mux_1) != 0) {
    debugtalk("bad1\r\n");
    NP32_SetLED_RGB(&neopixel_instance_internal, 0, color_red);
    NP32_Update(&neopixel_instance_internal);
		//HAL_GPIO_WritePin(DEBUG2_LED_GPIO_Port, DEBUG2_LED_Pin, GPIO_PIN_SET);
	}
  
  if (i2c_mux_reset(&tca_mux_2) != 0) {
    debugtalk("bad2\r\n");
    NP32_SetLED_RGB(&neopixel_instance_internal, 1, color_red);
    NP32_Update(&neopixel_instance_internal);
	}

  if (i2c_mux_reset(&tca_mux_3) != 0) {
    debugtalk("bad3\r\n");
    NP32_SetLED_RGB(&neopixel_instance_internal, 0, color_blue);
    NP32_Update(&neopixel_instance_internal);
	}

  
  

  // init device stack for tiny usb!!! https://docs.tinyusb.org/en/latest/integration.html ----------------------------------------------
	tud_cdc_write_clear();
  
  if (tusb_init(BOARD_DEVICE_RHPORT_NUM, NULL)) {
    debugtalk("inited tusb sucessfully\r\n");
  } else {
    debugtalk("bad4\r\n");
  }

  /* USER CODE END 2 */

  /* Infinite loop */
  /* USER CODE BEGIN WHILE */
  while (1)
  {
    /* USER CODE END WHILE */

    /* USER CODE BEGIN 3 */

    tud_task();

    //NP32_SetAllLEDs_RGB(&neopixel_instance_internal, color_red);
    //
    //tud_task();
    //debugtalk("looping\r\n");
    //HAL_Delay(1000U);
    //NP32_SetAllLEDs_RGB(&neopixel_instance_internal, color_blue);
    //NP32_Update(&neopixel_instance_internal);
    if (HAL_GPIO_ReadPin(GPIOG, GPIO_PIN_6) && runOneshot) {
      runOneshot = false;
      //PG6_BTN1_INT
      NP32_SetLED_RGB(&neopixel_instance_internal, 3+2, color_blue);
      //lcd_puts(&lcd, "Hello, LCD 1!");
      debugtalk("1");

      //char Buffer[25] = {0};
      //uint8_t i = 0;
      //HAL_StatusTypeDef rete;
      //
      //debugtalk("Starting I2C Scanning: \r\n");
      //uint16_t tmag_addr;
//
      //for (i=1; i < 128; i++) {
      //  rete = HAL_I2C_IsDeviceReady(&hi2c1, (uint16_t)(i<<1), 3, 5);
      //
      //  if (rete != HAL_OK) { /* No ACK Received At That Address */
      //    debugtalk(" - ");
      //  } else if(rete == HAL_OK) {
      //    sprintf(Buffer, "0x%X", i);
      //    //debugtalk("found it \r\n");
      //    debugtalk(Buffer);
      //    debugtalk("Done! \r\n");
      //    lcd_clear(&lcd);
      //  
      //    lcd_puts(&lcd, Buffer);
      //    tmag_addr = (uint16_t)(i<<1);
      //  }
      //}

      if (i2c_mux_select(&tca_mux_1, 0) != 0) {
        debugtalk("TMAG mux channel select failed\r\n");
        Error_Handler();
      }
    
      tmag_handles[0] = TMAG5273_CreateHandle(&hi2c1, 0x35);
      TMAG5273_Init(&tmag_handles[0]);

      char Buffer[50] = {0};

      // reading rotation from sensor
		  TMAG5273_Axis_t mag;
		  TMAG5273_Angle_t angle;
		  uint8_t ret = -1;

		  // reading sensor magnet pos. to output led/etc.
		  ret = TMAG5273_ReadMagneticField(&tmag_handles[0], &mag);
		  if (ret == 0) {
		  	sprintf(Buffer, "Bx = %.3f mT, By = %.3f mT, Bz = %.3f mT\r\n", mag.Bx, mag.By, mag.Bz);
        debugtalk(Buffer);
		  	sprintf(Buffer, "Return value: %u\r\n", ret);
        debugtalk(Buffer);
      }
      debugtalk("Buffer done");
    } else {
      runOneshot = true;
      NP32_SetLED_RGB(&neopixel_instance_internal, 3+2, color_black);
    }
    if (HAL_GPIO_ReadPin(GPIOG, GPIO_PIN_7)) {
      //PG7_BTN2_INT
      NP32_SetLED_RGB(&neopixel_instance_internal, 2+2, color_blue);
      lcd_puts(&lcd, "aaaaaaaaaaaaaaaaaaaa");
      debugtalk("2");
    } else {
      NP32_SetLED_RGB(&neopixel_instance_internal, 2+2, color_black);
    }
    if (HAL_GPIO_ReadPin(GPIOC, GPIO_PIN_7)) {
      //PC7_BTN3_INT
      NP32_SetLED_RGB(&neopixel_instance_internal, 1+2, color_blue);
      lcd_puts(&lcd, "ok bro");
    } else {
      NP32_SetLED_RGB(&neopixel_instance_internal, 1+2, color_black);
    }
    if (HAL_GPIO_ReadPin(GPIOA, GPIO_PIN_8)) {
      //PA8_BTN4_INT
      NP32_SetLED_RGB(&neopixel_instance_internal, 0+2, color_blue);
      lcd_puts(&lcd, "its not fair");
    } else {
      NP32_SetLED_RGB(&neopixel_instance_internal, 0+2, color_black);
    }
    //lcd_gotoxy(&lcd, 0, 1);
    
    NP32_Update(&neopixel_instance_internal);
    
    //debugtalk("looping\r\n");
    //HAL_Delay(1000U);
    
  }
  /* USER CODE END 3 */
}

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
 /* MPU Configuration */

void MPU_Config(void)
{
  MPU_Region_InitTypeDef MPU_InitStruct = {0};

  /* Disables the MPU */
  HAL_MPU_Disable();

  /** Initializes and configures the Region and the memory to be protected
  */
  MPU_InitStruct.Enable = MPU_REGION_ENABLE;
  MPU_InitStruct.Number = MPU_REGION_NUMBER0;
  MPU_InitStruct.BaseAddress = 0x0;
  MPU_InitStruct.Size = MPU_REGION_SIZE_4GB;
  MPU_InitStruct.SubRegionDisable = 0x87;
  MPU_InitStruct.TypeExtField = MPU_TEX_LEVEL0;
  MPU_InitStruct.AccessPermission = MPU_REGION_NO_ACCESS;
  MPU_InitStruct.DisableExec = MPU_INSTRUCTION_ACCESS_DISABLE;
  MPU_InitStruct.IsShareable = MPU_ACCESS_SHAREABLE;
  MPU_InitStruct.IsCacheable = MPU_ACCESS_NOT_CACHEABLE;
  MPU_InitStruct.IsBufferable = MPU_ACCESS_NOT_BUFFERABLE;

  HAL_MPU_ConfigRegion(&MPU_InitStruct);
  /* Enables the MPU */
  HAL_MPU_Enable(MPU_PRIVILEGED_DEFAULT);

}

/**
  * @brief  This function is executed in case of error occurrence.
  * @retval None
  */
void Error_Handler(void)
{
  /* USER CODE BEGIN Error_Handler_Debug */
  /* User can add his own implementation to report the HAL error return state */
  __disable_irq();
  while (1)
  {
  }
  /* USER CODE END Error_Handler_Debug */
}
#ifdef USE_FULL_ASSERT
/**
  * @brief  Reports the name of the source file and the source line number
  *         where the assert_param error has occurred.
  * @param  file: pointer to the source file name
  * @param  line: assert_param error line source number
  * @retval None
  */
void assert_failed(uint8_t *file, uint32_t line)
{
  /* USER CODE BEGIN 6 */
  /* User can add his own implementation to report the file name and line number,
     ex: printf("Wrong parameters value: file %s on line %d\r\n", file, line) */
  /* USER CODE END 6 */
}
#endif /* USE_FULL_ASSERT */

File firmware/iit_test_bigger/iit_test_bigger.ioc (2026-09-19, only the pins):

Mcu.UserName=STM32H743IITx
PA0.Signal=GPIO_Output
PA10.Signal=LPUART1_RX
PA11.Signal=USB_OTG_FS_DM
PA12.Signal=USB_OTG_FS_DP
PA2.Signal=GPIO_Input
PA4.Signal=I2S1_WS
PA6.Signal=I2S1_SDI
PA7.Signal=I2S1_SDO
PA8.Signal=GPIO_Input
PA9.Signal=LPUART1_TX
PB6.Signal=I2C1_SCL
PB7.Signal=I2C1_SDA
PC0.Signal=FMC_SDNWE
PC10.Signal=SDMMC1_D2
PC11.Signal=SDMMC1_D3
PC12.Signal=SDMMC1_CK
PC2_C.Signal=FMC_SDNE0
PC3_C.Signal=FMC_SDCKE0
PC7.Signal=GPIO_Input
PC8.Signal=SDMMC1_D0
PC9.Signal=SDMMC1_D1
PD0.Signal=FMC_D2_DA2
PD1.Signal=FMC_D3_DA3
PD10.Signal=FMC_D15_DA15
PD14.Signal=FMC_D0_DA0
PD15.Signal=FMC_D1_DA1
PD2.Signal=SDMMC1_CMD
PD8.Signal=FMC_D13_DA13
PD9.Signal=FMC_D14_DA14
PE0.Signal=FMC_NBL0
PE1.Signal=FMC_NBL1
PE10.Signal=FMC_D7_DA7
PE11.Signal=FMC_D8_DA8
PE12.Signal=FMC_D9_DA9
PE13.Signal=FMC_D10_DA10
PE14.Signal=FMC_D11_DA11
PE15.Signal=FMC_D12_DA12
PE2.Signal=GPIO_Output
PE3.Signal=GPIO_Output
PE4.Signal=GPIO_Output
PE5.Signal=GPIO_Output
PE7.Signal=FMC_D4_DA4
PE8.Signal=FMC_D5_DA5
PE9.Signal=FMC_D6_DA6
PF0.Signal=FMC_A0
PF1.Signal=FMC_A1
PF10.Signal=GPIO_Output
PF11.Signal=FMC_SDNRAS
PF12.Signal=FMC_A6
PF13.Signal=FMC_A7
PF14.Signal=FMC_A8
PF15.Signal=FMC_A9
PF2.Signal=FMC_A2
PF3.Signal=FMC_A3
PF4.Signal=FMC_A4
PF5.Signal=FMC_A5
PF7.Signal=GPIO_Output
PF8.Signal=GPIO_Output
PF9.Signal=GPIO_Output
PG0.Signal=FMC_A10
PG1.Signal=FMC_A11
PG11.Signal=I2S1_CK
PG15.Signal=FMC_SDNCAS
PG4.Signal=FMC_A14_BA0
PG5.Signal=FMC_A15_BA1
PG6.Signal=GPIO_Input
PG7.Signal=GPIO_Input
PG8.Signal=FMC_SDCLK
PH11.Signal=I2C4_SCL
PH12.Signal=I2C4_SDA
PH2.Signal=GPIO_Output
PH3.Signal=GPIO_Output
PH4.Signal=I2C2_SCL
PH5.Signal=I2C2_SDA
PI10.Signal=GPIO_Output
PI2.Signal=S_TIM8_CH4
PI3.Signal=GPIO_Output
PI4.Signal=GPIO_Output
PI5.Signal=GPIO_Output
PI6.Signal=GPIO_Output
PI7.Signal=GPIO_Output
PI9.Signal=GPIO_Output

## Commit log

2026-03-30 research and pcb
    [FTSH-107-01-L-DV-K-A.stp, mpe32board.kicad_pcb, mpe32board.kicad_sch]
2026-03-30 more pcb additions + research
    [mpe32board.kicad_sch]
2026-04-02 pcb i2c mux + connectors
    [BM04B-SRSS-TB--3DModel-STEP-1.STEP, BM06B-SRSS-TB--3DModel-STEP-56544.STEP, mpe32board.kicad_pcb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]
2026-04-14 add sdram
    [mpe32board.kicad_pcb, mpe32board.kicad_sch, sensor_connectors.kicad_sch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]
2026-04-25 layout stuff
    [472192001.stp, BM04B-SRSS-TB--3DModel-STEP-1.STEP, JST_SH_BM04B-SRSS-TB_1x04-1MP_P1.00mm_Vertical.step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]
2026-04-26 board layout stuff
    [microsd.kicad_sch, mpe32board.kicad_pcb, mpe32board.kicad_sch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]
2026-04-26 create lcd footprint
    [1x05 molex 1719710005.stp, debugdispcontrol.kicad_sch, mpe32board.kicad_pcb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]
2026-04-29 routed data bus of ram
    [Same_Sky_SJ-3524-SMT-TR.step, audioic.kicad_sch, debugdispcontrol.kicad_sch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]
2026-05-03 routed ram
    [audioic.kicad_sch, lcddisplay.kicad_sch, mpe32board.kicad_pcb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]
2026-05-04 routed audio codec and sdram
    [lcddisplay.kicad_sch, microsd.kicad_sch, mpe32board.kicad_pcb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]
2026-05-07 route connectors
    [mpe32board.kicad_pcb, mpe32board.kicad_sch]
2026-05-09 finish hacker header routing, drc checked
    [mpe32board.kicad_pcb, mpe32board.kicad_sch]
2026-05-09 silkscreen connectors
    [mpe32board.kicad_pcb]
2026-05-12 length match sdram
    [microsd.kicad_sch, mpe32board.kicad_pcb, mpe32board.kicad_sch]
2026-05-13 drc checks n more
    [mpe32board.kicad_pcb]
2026-05-17 silkscreen for main board + finished sensor board
    [1x05 molex 1719710005.stp, 472192001.stp, BM06B-SRSS-TB--3DModel-STEP-56544.STEP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]
2026-05-26 add sensor and readme
    [mpe32board.kicad_pcb, mpe32board.step, mpe32sensor.kicad_pcb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]
2026-06-08 fixed/added tinyusb to proj
    [main.c]
2026-06-08 add i2c mux and neopixel hal libs
2026-06-10 readme add stuff
    [mpe32board.kicad_pcb]
2026-06-10 add jlcpcb carts and organize screenshots
    [bom-JLCPCB Assembly Order.xls, bom.csv, designators.csv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]
2026-06-10 add bom
    [bom.csv]
2026-06-22 add lcd level shifter, lm1117 ldo
    [lcddisplay.kicad_sch, microsd.kicad_sch, mpe32board.kicad_pcb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]
2026-06-24 fix power scheme and add usb diode + more
    [mpe32board.kicad_pcb, mpe32board.kicad_sch]
2026-06-24 add stl
    [Case_mpe32board full part.stl]
2026-06-28 remove production files
    [bom.csv, designators.csv, mpe32board.kicad_pcb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]
2026-06-28 add final prod files
    [bom.csv, designators.csv, mpe32sensor.kicad_pcb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]
2026-08-12 Update README with sample code link for mpe32sensors
    Added a link to sample code for mpe32sensors on Arduino.
2026-09-02 production file changes + ide setup
    [audioic.kicad_sch, bom.csv, debugdispcontrol.kicad_sch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]
2026-09-07 fix/add dma and timer for neopixel io
    [iit_test_bigger.ioc]
2026-09-16 add button code, fix sdram config
    [iit_test_bigger.ioc, main.c]
2026-09-16 fix sdmmc setup and init
    [iit_test_bigger.ioc, main.c]
2026-09-17 add i2c led support
2026-09-19 hall effect implementation proof of concept
2026-09-22 half working poc multiple hall sensors
2026-10-09 24x sensor scanning, code refactors
2026-10-13 add oneshot button logic
2026-10-14 code refactoring and midi prototype
2026-10-16 fix midi mapping to reflect pcb markings
2026-10-16 better velocity calculation on log scale
2026-11-07 tmag sensor init fix
2026-11-07 400hz i2c fast

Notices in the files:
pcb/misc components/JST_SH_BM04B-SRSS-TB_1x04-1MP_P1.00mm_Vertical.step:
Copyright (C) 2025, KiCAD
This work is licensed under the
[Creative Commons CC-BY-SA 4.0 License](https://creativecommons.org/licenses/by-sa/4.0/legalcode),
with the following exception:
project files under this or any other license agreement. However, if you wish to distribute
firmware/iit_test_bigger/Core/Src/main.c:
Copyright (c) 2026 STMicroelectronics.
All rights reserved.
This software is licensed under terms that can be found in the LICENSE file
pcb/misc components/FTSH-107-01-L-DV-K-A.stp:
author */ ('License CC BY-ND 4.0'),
